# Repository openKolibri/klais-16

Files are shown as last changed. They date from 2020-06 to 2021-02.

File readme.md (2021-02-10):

![SIXTEEN]
![SEGMENT]
![DISPLAY]

# Sixteen Segment Display
The look of classic signage, be it neon tubes, wrought iron, or the use of distinctive typography and negative space, has a particular appeal. Unfortunately, the art form is dwindling due to the flexibility and flash that comes with newer LED arrays. Their distinctive styles have been giving way for the monotony of RGB LED panels.

![cycleGif]

The *Klais Display* series, in which this panel is the first item, was inspired by the early electronic displays still seen in relics bygone from an era of cigarette machines, electronics test equipment, and pinball machines. Its been modernized, enlarged, and made easily integrable into your own projects, while retaining its beauty and elegance.

![isoArray]

What follows below is highly detailed technical documentation. The [user guide][userGuide] is also available and focuses on integrating the display(s) into a project.

## Table of Contents
  * [Design](#design)
    * [Hardware](#hardware)
      * [LEDs](#leds)
      * [LED Driver](#led-driver)
      * [Microcontroller](#microcontroller)
      * [Power supply](#power-supply)
      * [Connections](#connections)
        * [Programming](#programming)
        * [Dataflow](#dataflow)
        * [Config Pads](#config-pads)
        * [Key Connector](#key-connector)
      * [Mounting](#mounting)
    * [Firmware](#firmware)
      * [Modes](#modes)
      * [UART](#uart)
        * [RX](#rx)
        * [TX](#tx)
      * [Brightness](#brightness)
      * [Timeout Refresh](#timeout-refresh)
      * [Display Driver](#display-driver)
        * [Protocol](#protocol)
        * [LED Number](#led-number)
        * [Segment Order](#segment-order)
      * [Configuration](#configuration)
        * [Baud Selection](#baud-selection)
      * [Compiling](#compiling)
      * [Flashing](#flashing)
  * [Absolute Maximum Ratings](#absolute-maximum-ratings)
  * [Guaranteed Ratings](#guaranteed-ratings)
  * [Manufacturing](#manufacturing)
    * [BOM](#bom)
    * [PCB-Assembly](#pcb-assembly)
    * [Physical Assembly](#physical-assembly)
    * [Production Scaling](#production-scaling)
      * [PCB Stack](#pcb-stack)
      * [Die Cut](#die-cut)
      * [Injection Moulding](#injection-moulding)
      * [Custom ASIC](#custom-asic)
    * [Programmer](#programmer)
      * [Minimal](#minimal)
      * [Production](#production)
    * [Artwork](#artwork)
    * [Labels](#labels)
    * [Inventory and QC](#inventory-and-qc)
    * [Part Numbers](#part-numbers)
  * [Safety](#safety)
  * [Certifications](#certifications)
  * [Licence](#licence)
  * [Attribution](#attribution)
    * [Fonts](#fonts)
    * [Libraries](#libraries)
  * [Reccomended Reading](#reccomended-reading)
  * [ToDo](#todo)

## Design
The display is a recreation of sixteen segment alphanumeric displays in a format that is physically larger and thinner than anything available on the viewing front. The modular segments can be combined to make a display of any length. It is designed to be easy to use and accessible. The physical design is based on stacking layers to provide clearance, a diffusion layer, and encapsulation for the electronics. The minimalist design and 3:2 aspect ratio were chosen to make integration very clean. There are no gaps between characters and when placed side-by-side, there is a flat near-seamless surface.

| NOON | MDNT | BASE |
| --- | --- | --- |
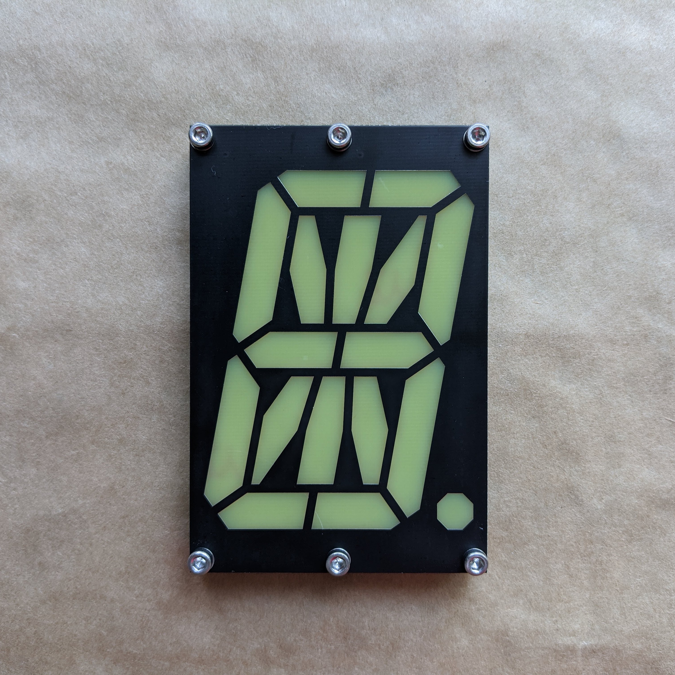
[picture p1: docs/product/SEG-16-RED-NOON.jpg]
SEG-16-RED-NOON
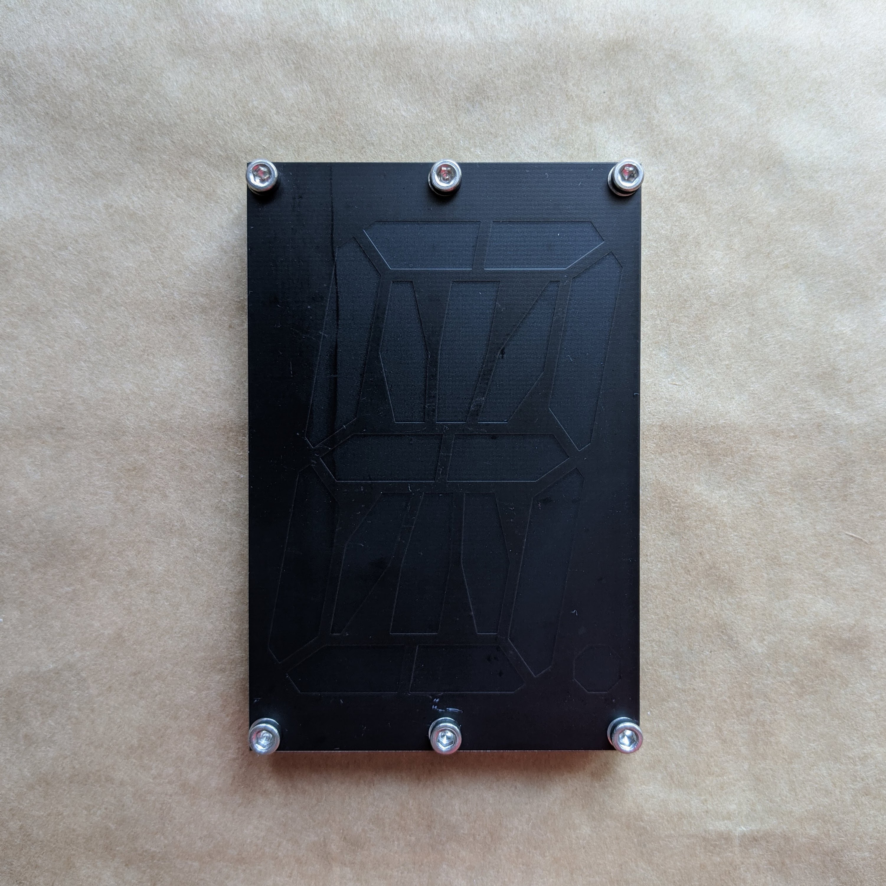
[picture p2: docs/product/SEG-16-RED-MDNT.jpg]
SEG-16-RED-MDNT
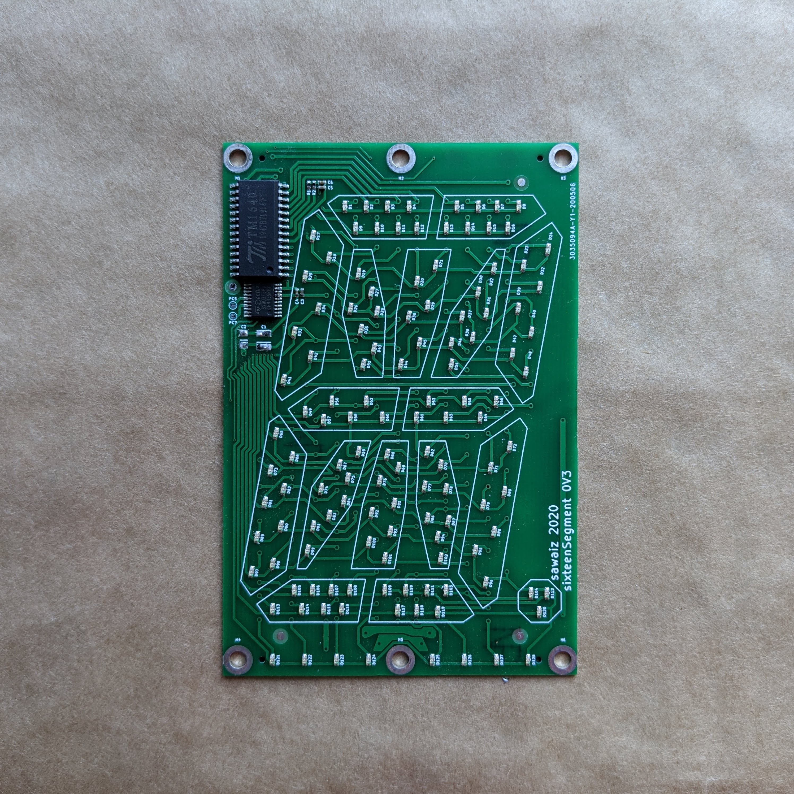
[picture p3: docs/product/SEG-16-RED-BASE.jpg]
SEG-16-RED-BASE
|  |  |  |

### Hardware
The panels are designed for efficient high yield manufacturing in both small and large quantities, with three possible stages, based on tooling investment. The physical size of each panel is `100 mm` x `66.66 mm`, providing a 3:2 aspect ratio and are nominally `5.8 mm` thick. Each panel weighs `63.97 g` with 6 plastic rivets.

![schematic]

A [schematic.pdf] is also available.

#### LEDs
The assembly uses 128 0603 surface mount LEDs. They are spaced evenly through all the segments, as well as eight of them acting as points in the underline. The 0603 (`60 mil` x `30 mil`, or `1.5 mm` x `0.8 mm`) package is used for their wide accessibility, providing a breadth of alternatives in color, lens projection angle, and brightness for possible substitutions. The datasheets for the LEDs used for each model is provided in the table below.

| Model | MPN | Detail | Current Draw |
| --- | --- | --- | --- |
| `SEG-16-RED-XXXX` | [KT-0603R] | ![IMG-KT-0603R] | [RED][asciiCurrent]  |

#### Led Driver
Titan Micro Electronic's [TM1640] ([english][TM1640ENG]) is used to control the LEDs. The device provides individual control of 128 LEDs in a 16x8 multiplexing configuration, has 8 levels of brightness adjustment, and provides a constant current supply of `20 mA`. It is rated for only `5V` but testing shows that, although with a slightly lower multiplexing frequency, it works quite well at `3.3V`. Communication is over a clocked serial link with a custom protocol and register mappings control the outputs. The 16 grids are rows, while the eight segments are the columns.

![IMG-TM1640]

This chip is made specifically for the Chinese market and may be hard to source in the west. Based on datasheets, it is easily swappable with identical components from other manufacturers, as shown below, in case the availability changes.

| Manufacturer | MPN |
| --- | --- |
| GN Semiconductors | GN1640 |
| Cmsemicon | CMS1640  |
| Wuxi I-CORE Electronics | AiP1640  |

#### Microcontroller
STMicroelectronics's [STM8S003] is a very low-cost microcontroller for cost sensitive applications, but provides a reasonable host of features. It has a wide voltage range of `2.95V` to `5.5V`, internal 16Mhz clock, UART that can be clocked at up to 1Mbps, plenty of timers, and 28 I/O. As well as other features that are not being used like a 10b ADC, SPI/I2C hardware, and low power modes.

![IMG-STM8S003]

#### Power supply
The input power is rated at `5V`, and the current drawn is dependent on the number of lit LEDs and the color of the display. Each segment has `100 uF` + `10 uF` of bulk capacitance, as well as decoupling on all the chips so it should be robust against a unstable power supply. There is no reverse polarity or overvoltage protection as that is the responsibility of the integrator. The table below shows some current draws, with the full table of all the models and characters [available][asciiCurrent] along with measurement methodology.

| Display  | `RED` Full Brightness (mA) | `RED` Min Brightness (mA) |
| --- | ---:| ---:|
| Off | 5.2 | 5.2 |
| All | 319.0 | 28.6 |
| `@` | 197.0 | 19.1 |
| `.` | 17.1 | 6.0 |
| `K` | 125.7 | 13.8 |
| `[` | 106.0 | 12.4 |

Maximum power draw is `1.6 W` at max brightness and all segments lit. Temperature rise above ambient after two hours is `15.9°C` (`61°F`).

#### Connections
The back of the module contains pads that are used for communication and configuration, providing many options to the end-user.

![config-back]

##### Programming
The four labeled pads near the top of the module are for programming. The STM8S uses a `SWIM` programming interface. The `4 mm` round pads are used to install the initial firmware and can be used for firmware updates or custom firmware if needed. The power pins are connected to the power rails, so they can also be used as power input or outputs.

![config-pgrm]

##### Dataflow
The five pads on each side are the connections that provide the data, as well as power rails, from one board to another. For basic functionality, lining up the boards and soldering the top three pads (`GND`, `TX/RX`, and `+5V`) is all that is needed, although soldering all five will provide more power rails and cause no issues.

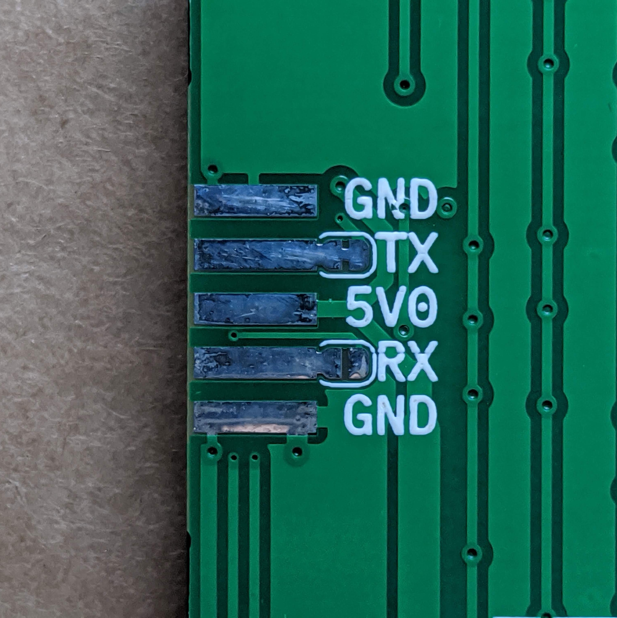
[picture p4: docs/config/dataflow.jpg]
config-dataflow


With the display facing you, the data comes in on the left on the `RX` pad, and flows out on the right via the `TX` pad. If the modules are soldered inverted, the connection is symmetric providing protection against swapping power supply rails.

If needed, the inverted configuration also provides the option of having two decimal points forming a colon. For this configuration to work, the solder jumper pads on the back will need to be reconfigured, cutting the top two and bridging the bottom, as shown in the diagram.

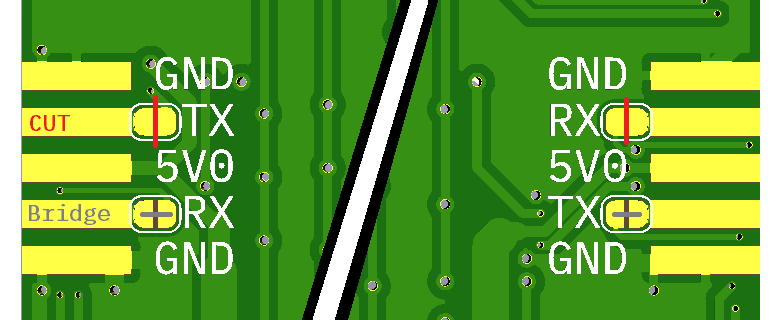
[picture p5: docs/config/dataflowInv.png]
config-dataflowInv


The moves the `RX` and `TX` lines to the correct sides to be placed inline with normally oriented modules.

##### Config Pads
The back has seven configuration pads that provide different settings and are checked on boot. By default, they are all unbridged. The configuration pads are to be selected with solder jumpers.

![config-config]

##### Key Connector
The front contains two optional unpopulated spring connectors Molex [0472861001]. These provide functionality if the thickness of the panel or reconfigurability is the main concern. By removing any solder joints on the back, and transmitting the data and power through the keyed connector. The thickness is limited to `5.8 mm`. The small PCB keys also allow assembly and construction of quick and easily reconfigurable arrays. The connectors are not always used, so they are not installed by default since they add cost and are not expected to be used by most.

![config-keyed]

The solder jumper marked `RTN_EN` enables the return channel on the last board. If a chain of displays is used and needs to be chained to the next row, this will send the signal back though one of the spring connector pins and make it available on the first display making a for a cleaner run of signal between rows.

#### Mounting
The mounting holes are placed `3 mm` from all edges and are for `M3` screws in a very close fit with a `3.1 mm` drill and though plated for a bit more ruggedness. A `#4` screw can be used as a imperial alternative. They are not connected to any nets, have a `5.5 mm` annular ring for screw heads, and are masked so if screws are not used, the annular ring surface matches the rest of the panel.

![mountingDim]

The holes and hardware provide a number of options for assembly and mounting.

| Mounting Method | Part Number | Component | Example |
| --- | --- | --- | --- |
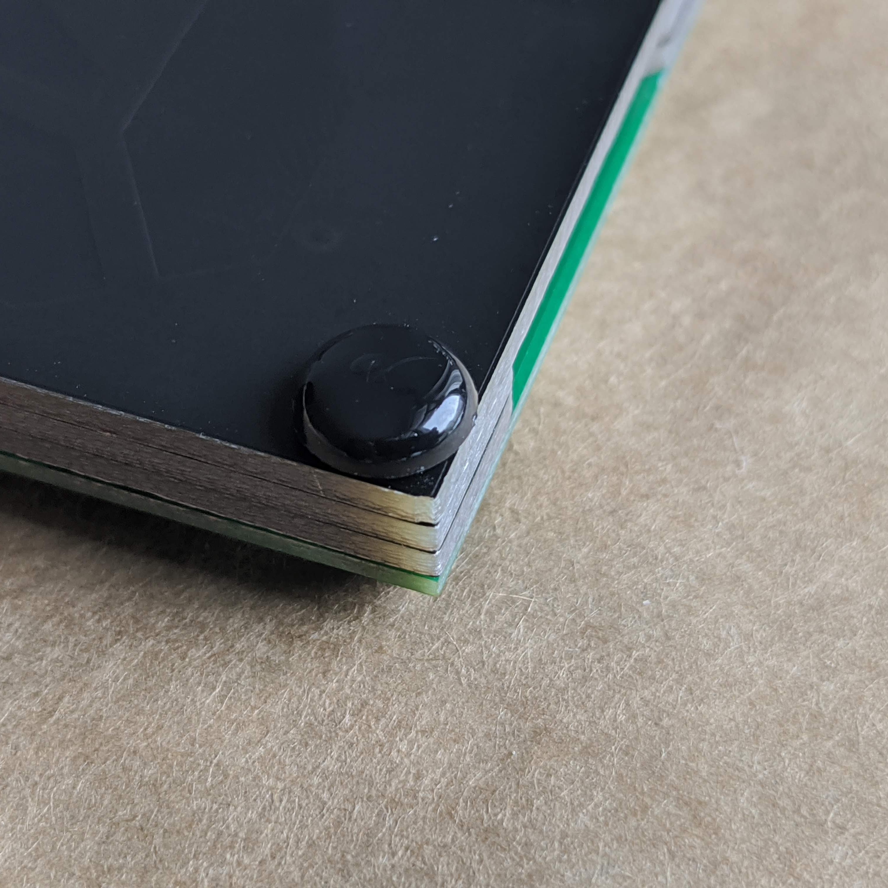
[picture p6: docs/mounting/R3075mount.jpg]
rivetInstalled
| Push Rivet `3 mm` x `7.5 mm` | [R3075] | ![plasticRivet] |  |
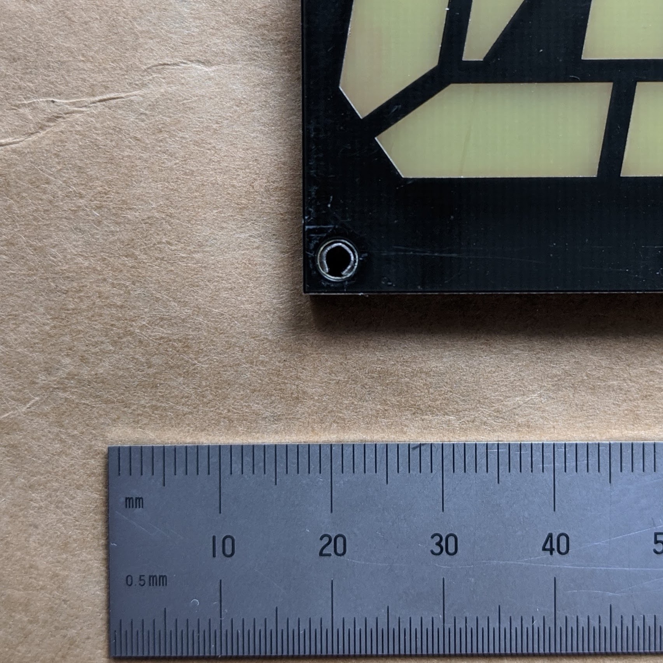
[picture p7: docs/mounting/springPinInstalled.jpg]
springPinInstalled
| Spring pin `3 mm` x `6 mm` | [97161A128] | ![springPin] |  |
| `M3x8x0.5` and Nut | [91292A112] [91828A211] | ![M3x8] | ![M3x8Installed] |
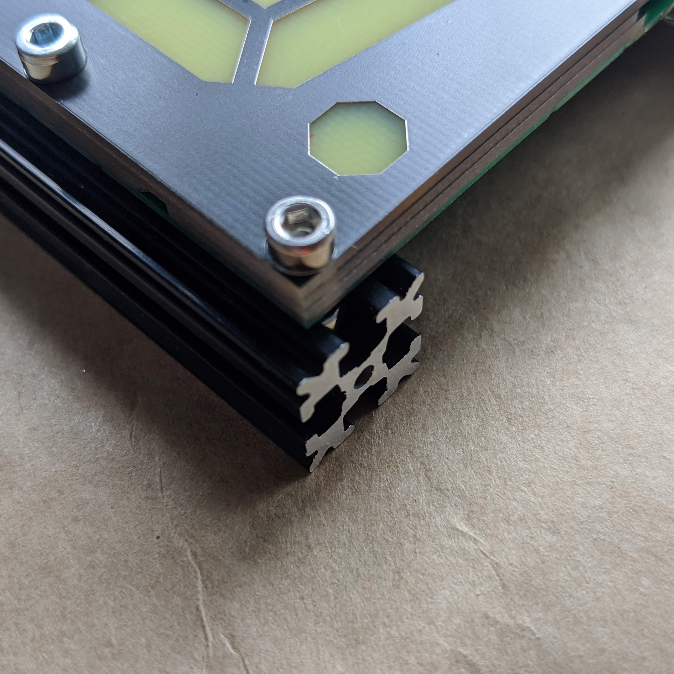
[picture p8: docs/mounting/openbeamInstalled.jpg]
openbeamInstalled
| `15 mm` Extrusion M3x10 | [Misumi HFS3], [OpenBeam], [Makerbeam XL] | ![openbeamParts]  |   |
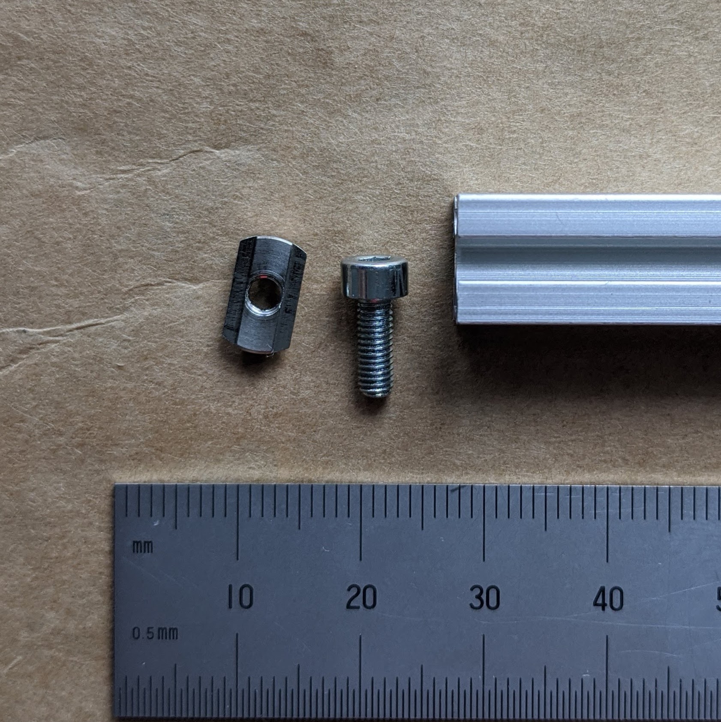
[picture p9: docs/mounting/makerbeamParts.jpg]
makerbeamParts
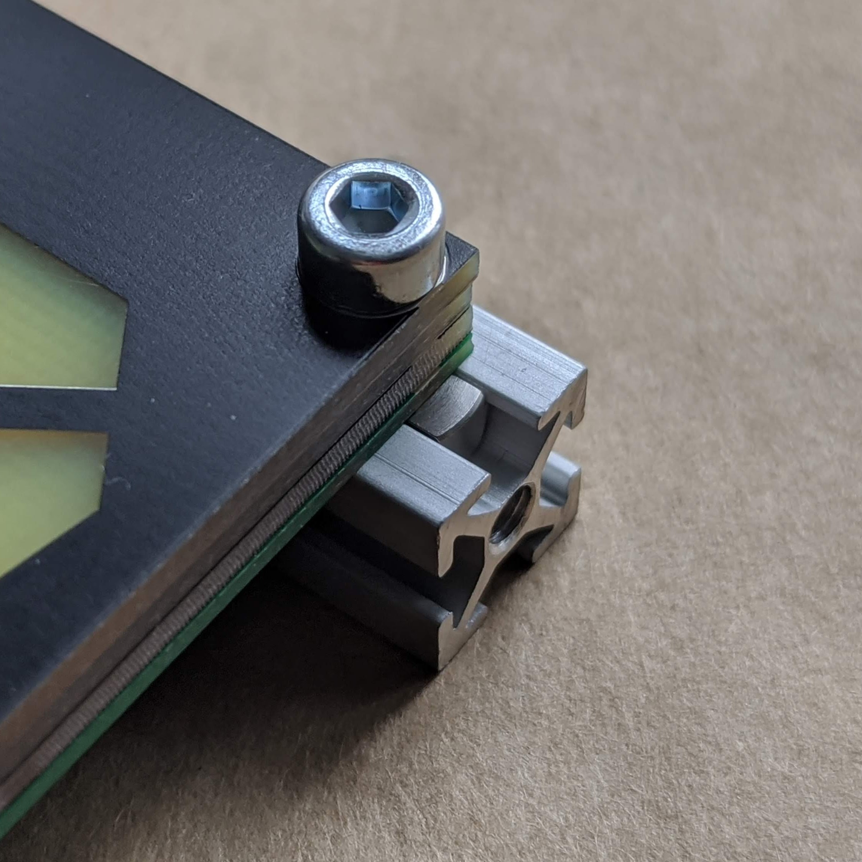
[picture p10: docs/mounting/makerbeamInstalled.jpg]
makerbeamInstalled
| `10 mm` Extruison M3x8 | [MakerBeam], [MicroRAX] |  |  |
| `20 mm` Extrusion Slot | [Misumi HFS5], [Metric 8020] | ![2020Extrusion]  | ![2020Installed] |
| Soldered brass nut | [90690A037] | | |
| Zip Ties `3 mm` | | | |
| #4 screw, machine or wood | | | |
| Pop rivets, M3 or #4 | | | |

### Firmware
The firmware is written in C and is fully interrupt driven. It uses the [STM8 standard periphiral library][STM8SPL] (SPL) and provides multiple modes of controlling the display through commands. All code shown is simplified pseudocode.

#### Modes
By default the display boots in the `ASCII` character mode operating as a state-machine making changes based on each byte received. When enough bytes have been received for the command, the device shifts back into `ASCII` mode.

| Mode | Control Byte | Bytes | Notes |
| --- | --- | -----:| --- |
| ASCII | None | 0 | Displays ASCII cahrachter |
| Segment | 0x11 `DC1` | 3 | Control individual segments |
| LED | 0x12 `DC2` | 16 | Control individual LEDs |
| Brightness | 0x13 `DC3` | 1 | Set brightness |

**Only ASCII mode is verified in firmware version 0.6 other modes are in beta**

#### UART
The UART hardware is used to receive and transmit data from a module to another. Communication is through an 8 bit NRZ with one start bit and one stop bit encoding with no parity and the default baud rate is `115200 bps`. The voltage levels are the module power voltage, nominally `5V`.

The UART is initialized on boot and the receive interrupt is enabled. When a new character has been read in the receive buffer, the interrupt fires.

##### RX
Based on the receive mode the new data is loaded into the receive buffer. A number of consecutive bytes read is dependent on the mode that is set. A mode byte received after mode has been reset will change the mode as well. The transmit interrupt is fired when a new byte is received and the buffer is full, depending on the current receive mode.

##### TX
The first byte is sent by the interrupt trigger. Depending on the transmit mode, the interrupts continue to fire, stepping down through the buffer until it is empty, outputting the data in the same order as it was received.

#### Brightness
There are nine brightness levels including blanking. They are accessed with sending the brightness mode selector followed by the brightness code.

| Level | Code (HEX) | Code (DEC) |
| -----:| --- | ---:|
| OFF | 0x81 | 129 |
| 1 | 0x88 | 136 |
| 2 | 0x89 | 137 |
| 4 | 0x8A | 138 |
| 10 | 0x8B | 139 |
| 11 | 0x8C | 140 |
| 12 | 0x8D | 141 |
| 13 | 0x8E | 142 |
| 14 | 0x8F | 143 |

#### Timeout Refresh
A display refresh timeout is implemented so the display only updates when there is a pause in the data. This prevents the display from flickering with intermediate data when a stream of data is being loaded into an array. This also updates all displays at the exact same time, since the time from the last byte is the same across all displays in an array.

```c
UART_RX_INTERRUPT() {
  TIMER_SET(0x00);
  TIMER(INTERRUPT, ENABLE);

  // Remaining RX routine ...
}
```

Every time a new character is received in the RX buffer, a timeout is started of 1 ms (*to be replaced with 2.5 byte time based on baud rate*). If a new character comes before the timeout is reached, it is reset again. When the timeout is reached, the overflow interrupt is triggered. In the interrupt, the further interrupts are disabled and then the display is drawn based on the TX mode.

```c
TIMER_INTERRUPT(){
  TIMER(INTERUPT, DISABLE);
    switch (txMode) {
        case LED_CONTROL:
          showLeds(data);
          break;
        case SEGEMENT_CONTROL:
          showSegments(data);
          break;
        case BRIGHTNESS_CONTROL:
          setBrightness(data);
          break;
        default:
          showLetter(data);
    }
}
```

#### Display Driver
The display driver is a minimal custom library. The display driver is controlled over a clocked serial link with a custom protocol. The LEDs are multiplexed based on the internal memory that stores a 1b value for each LED.

The chip has only a few registers, most of which make up the current LED states. They are all described in the header file and fall into three sections.

- Data Commands
- Grid Memory
- Display Brightness

##### Protocol
A few requirements define the protocol.

- Default state for both clock and data is high
- Start condition is data going low followed by clock going low
- A bit is read when the clock is pulsed positive
- Data cannot change while clock is high
- End condition is clock high followed by data high
- 8 bits per byte, LSB First

![TM1640Timing]

Registers are set by sending a command byte followed by a optional data byte based on the command. A set of commands can be sent if auto increment mode is set by not fulfilling the end condition and sending the next byte immediately.

![dataCapImg]

A Saleae logic [capture][dateCapFile] is also provided.

##### LED Number
The LEDs are placed in a grid-like pattern, so a conversion is needed to map each LED to the segment it's in. [segmentMapping.h] contains arrays that map the LED's reference designator to each segment. This still needs to be converted into the segments and grid from the LED number. The formula below is used to make those conversions.

```
GRID = ((REF-1) / 8) + 1
SEG = (REF-1) % 8
```

##### Segment Order
Besides direct control over the LEDs, there are also helper functions such as segment control and print letter. These use the [segmentMapping.h] and [sixteenSegments.h] headers. Once the LEDs are mapped to the segments, the segments are mapped to the ASCII character set. [sixteenSegments.h] contains which segments need to be lit for each character, the notation used in both files refers to the segments in clockwise order going in as-is conversion with sixteen segment displays.

![segmentMap]

#### Configuration
On boot, the seven GPIO for the configuration pads have their internal pullups enabled and are then set as inputs. They are all sampled. Any that have been bridged to ground will read as low and their inverted state can be used to set the configuration.

```c
  uint8_t config = 0x00;
  config |= !read(PIN_0) << 0;
  config |= !read(PIN_1) << 1;
  config |= !read(PIN_2) << 2;
  config |= !read(PIN_3) << 3;
  config |= !read(PIN_4) << 4;
  config |= !read(PIN_5) << 5;
  config |= !read(PIN_6) << 6;
```

The pads have functions attached to them, some are just switches, while others join together in a binary segment to allow multiple selections.

| Pad | Function | Status |
| ---:| --- | --- |
| 0 | Inverted Display | Not implemented |
| 1 | Baud (Bit 3) | Implemented in 0.6 |
| 2 | Baud (Bit 2) | Implemented in 0.6 |
| 3 | Baud (Bit 1) | Implemented in 0.6 |
| 4 | Baud (Bit 0) | Implemented in 0.6 |
| 5 | Pending | Open for Development |
| 6 | Pending | Open for Development |

##### Baud Selection
Pads `[4:1]` allow baud selection, the default is `115200` as it is a common bitrate that is available on most computer and microcontrollers and is reasonably fast for most applications.

| Pad 4 | Pad 3 | Pad 2 | Pad 1 | Selected Baud |
| -----:| -----:| -----:| -----:| ---:|
| 0 | 0 | 0 | 0 | 115200 |
| 0 | 0 | 0 | 1 | 110 |
| 0 | 0 | 1 | 0 | 300 |
| 0 | 0 | 1 | 1 | 600 |
| 0 | 1 | 0 | 0 | 1200 |
| 0 | 1 | 0 | 1 | 2400 |
| 0 | 1 | 1 | 0 | 4800 |
| 0 | 1 | 1 | 1 | 9600 |
| 1 | 0 | 0 | 0 | 19200 |
| 1 | 0 | 0 | 1 | 38400 |
| 1 | 0 | 1 | 0 | 57600 |
| 1 | 0 | 1 | 1 | 128000 |
| 1 | 1 | 0 | 0 | 230400 |
| 1 | 1 | 0 | 1 | 256000 |
| 1 | 1 | 1 | 0 | 460800 |
| 1 | 1 | 1 | 1 | 1000000 |

It is tested with a 4 bit mask and right-shifted to get numbers 0-15 from the config byte.
```c
uint32_t bauds[16] = {115200, 110, /*...*/, 460800, 1000000};
uint32_t baud = bauds[(config & 0X1E) >> 1];
```

#### Compiling
It is setup to be compiled through [PlatformIO]. More information can be found through its [documentation][platformIODocs]. Changes may be made to the settings in the `ini` file.

#### Flashing
The [programming pads](#programming) on the back are used to program the module. An ST-Link V2 with the SWIM protocol is used to upload the firmware.

Uploading using PlatformIO is currently used. Refer to [documentaiton][platformIODocs]. Changes may be needed to the `ini` file settings.

We also use a custom bash script internally that uploads, tests, and updates our database. It uses STM8Flash on Linux machines and ST Visual Programmer on WSL.

## Absolute maximum ratings
**To be tested, don't have the power supply, or really the heart to kill a module just yet.**

Works fine down to 3.3V.

## Guaranteed ratings

| Mesurement | Value | Unit | Tolerence |
| --- | -----:| ---- | --- |
| Power Supply | 5.0 | V | ± 0.2 |
| Max current  | 319 | mA | ± 5% |
| Max Temp | 60 | C | |
| Min Temp | -20 | C | |

## Manufacturing
Designing for manufacturing was a large portion of this project. This was done through many approaches on a number of fronts.

### BOM
The BOM was selected with parts that are common to the Chinese high-volume manufacturing market, have strong supply chains, as well as many alternatives in case a supplier stops manufacture. The number of unique parts was kept to a minimum and the maximum amount of features can be implemented with "free" options, like SMD pads. The table of BOM is shown below.

| REF | QTY | Manufacturer | MPN | Description |
| --- | ---:| --- | --- | --- |
| C1 | 1 | AVX | TAJB107K006RNJ | CAP: Tantalum 100uF 6.3V CASE-B_3528 |
| C2 | 1 | AVX | TAJA106K016RNJ | CAP: Tantalum 10uF 16V CASE-A_3216 |
| C3 C6 | 3 | Samsung Electro-Mechanics  | CL05A105KA5NQNC  | CAP: MLCC 1uF 25V 0402 |
| C4 C5 C7  | 2 | Samsung Electro-Mechanics  | CL05B104KO5NNNC  | CAP: MLCC 100nF 16V 0402 |
| D1-D128 | 128 | Hubei KENTO Elec | KT-0603R | LED: RED 520-625nm 90-100mcd@20mA 0603 |
| R1 R2 | 2 | Uniroyal Elec | 0402WGF1002TCE | RES: 10K 1% 1/16W 0402 |
| U1 | 1 | STMicroelectronics | STM8S003F3P6TR | MCU: 8b 16Mhz 8k Flash 128B EEPROM TSSOP-20 |
| U2 | 1 | Shenzhen Titan Micro Elec  | TM1640 | DRV: 16x8 LED Driver SOP-28 |

The [Octopart] BOM is also available, although not much use since the parts are not carried by US distributors.

### PCB-Assembly
The PCB assembly is single-sided surface mount components only. The smallest components are 0402. All can be PNP from tapes or tubes, and reflowed at once. There are three fiducials as well as three tooling holes on each board. The tooling holes are `1.152 mm` and the fiducials are `1.5 mm` x `3 mm`. There are 139 components all of which are SMD, yielding a total of 322 solder joints.

![assembly]

### Physical Assembly
The panels are combined in order and can be held together with `3 mm` x` 7.5 mm` nylon 6/6 push rivets. This makes ingress into inventory much faster, and gives the customer another option to use for mounting since it's an uncommon part.

### Production Scaling
The physical assembly varies in the volume of production. Further sections will be updated with information if we ever reach those volumes.

#### PCB Stack
First iteration is the PCB stack as that has no tooling cost and all can be order from the same manufacturer. There are four PCBs in the stack that make-up the display.

| Board | Height (mm) | Width (mm) | Layers | Copper  | Thickness (mm) | Material | Min Drill (mm) | Trace Sizing | Mask  | Silk | E-Test |
| ----- | ---:| ---:| ---:| ---:| ---:| --- | ---:| ---:| ----- | --- | --- |
| L0 | 100.00 | 66.66 | 2 |  1.0 oz | 1.0 | FR4 | 0.3 | 6/6 | Green |  White | Yes |
| L1 | 100.00 | 66.66 | 2 |  1.0 oz | 1.6 | FR4 | N/A | N/A | Black |  White | No |
| L2 | 100.00 | 66.66 | 2 |  1.0 oz | 1.6 | FR4 | N/A | N/A | Black |  White | No |
| L3 | 100.00 | 66.66 | 2 |  1.0 oz | 1.6 | FR4 | N/A | N/A | Black |  White | No |

The bottom board is the electrical board containing all the components and signals, and is used for all iterations. The following two boards provide spacing and separation for the diffusion of the LEDs, as well as cut outs for the other components, and the final board provides diffusion and a solid panel for the front face. The layout of each layer is shown in the table below.

| L0  | L1  | L2  | L3  |
|:-----:|:-----:|:-----:|:-----:|
| ![L0] | ![L1] | ![L2] | ![L3] |

PCB stack is best for quantities below 500 units.

#### Die Cut
The die cut panels replace the top three panels with `1/16"` plastic that is die cut. This is faster to manufacture and less expensive, since we do not need the copper, silk, or mask layers. Also, uses a through-opaque material instead of the FR4 providing better protection from light bleed.

| L1 | L2 | L3 |
|:---:|:---:|:---:|
| ![L1-DIE] | ![L2-DIE] | ![L3-DIE] |

Switch to die cut at 1k-10k units.

#### Injection Moulding
Injection moulded panel will replace the front three panels with a single injection moulded plastic part, as well as the screws. Providing the option to either punch through from the front to get the same M3 holes, or screw in from the back to have a completely clean front panel. The IM part also provides other benefits, such as, a more consistent texture on the whole panel, and a high contrast front that has no discernible pattern when off.

![imProto]

A test model was made with 2.5 deg draft angles and `1.2 mm` wall thickness for ABS moulding. Approximate calculations show tooling costs of $7.5k for production steel tooling, and 15s cycle time.

Switch to IM at 20k-100k units.

#### Custom ASIC
Flipchip LEDs with COB fully integrated controller. HDL gateware design to begin at 50k units. RISC-V processor with 16x16 multiplexing LED array at a 72 MHz PLL clock.

[Hey, a girl can dream. Chip die image]

Engineering and silicon die cost around $50k tooling (maybe? I don't really know, but I could probably synthesize a sea of gates design that works) Switch to custom ASIC at 100k units.

### Programmer
The chip needs to be programmed with the firmware and tested for proper operation before sending out to customers. Two programmers are designed. First, a low cost simple programmer for smaller quantities and available on special request for those who want to customize the firmware, and the other is a completely independent production-ready programmer and tester.

#### Minimal
Them minimal program has holes for alignment corresponding to the top row, and four spring pins. These connect out to the programming header which can then be corrected to an ST-Link V2. The alignment holes have M3x8 screws and nuts which were added to create alignment pins. The board to be programmed is aligned with the pin and held down while programming.

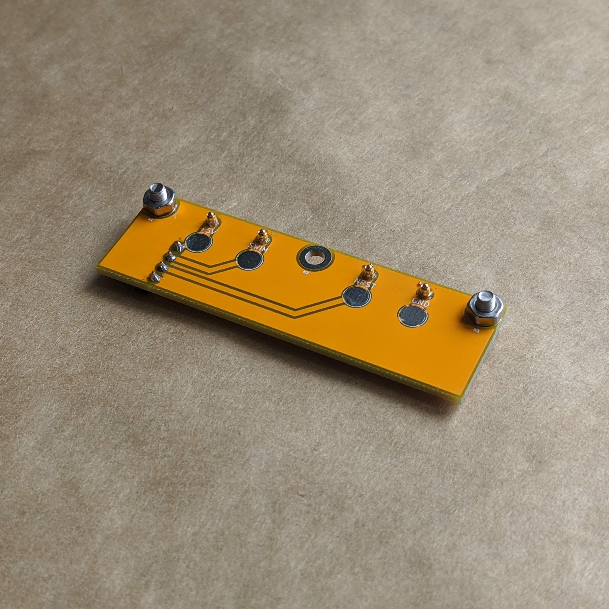
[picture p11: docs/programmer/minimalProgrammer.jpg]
minimalProgrammer


#### Production
The production programmer is a program and test jig. The boards are slipped under the bottom overhang and pushed down until the lever snaps and holds them in place. Then a full test suite can be run, checking the input and output, programming with multiple firmwares and reading back system outputs to verify that the device works properly.

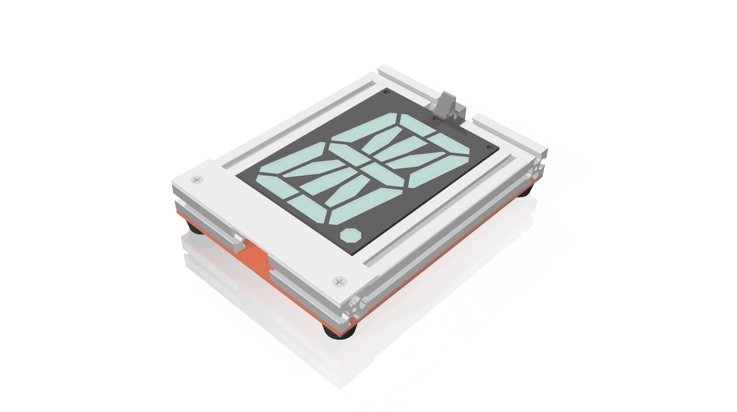
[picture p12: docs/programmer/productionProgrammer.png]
productionProgrammer


### Artwork
The artwork on the back is a trademark and protected by copyright. This can not be duplicated on derivative works. It consists of the Kolibri bird, copyright and designer notices, certifications, a location for labeling, as well as the URL and QR code to documentation.

### Labels
The back has a location for a `38 mm` x `13 mm` label from a Brother `38 mm` continuous label. This label can have serial number, batch numbers, the model number, and any other device specific information.

![config-label]

### Inventory and QC
Inventory can then be managed with QR coded serialized tags. The serialization also provides better QC as it allows failure analysis and tracking in case of issues traceable to the batch and assembly level.

### Part Numbers
The manufacturer part number is based on the following scheme.

MPN: `SEG-16-AAA-BBBB`

Where `AAA` is the three character code for color

| Code | Color |
| --- | --- |
| `RED`  | Red |
| `GRN`  | Green |
| `BLU`  | Blue |
| `RGB`  | Red Green Blue |
| `WHT`  | White (5000k) |
| `WWT`  | Warm White (3500k) |
| `YEL`  | Yellow |

And `BBBB` denotes the face type

| Code | Face Type |
| --- | --- |
| `NOON` | Noon face, Exposed FR4 |
| `MDNT` | Midnight face. Black soldermask |
| `PLEX` | Acrylic Laser Cut |
| `IM  ` | Injection Moulded |

## Safety
The assembly is almost exclusively made from FR4. It is highly fire retardant and will not burn after a flame is removed.

The edges are milled, but it is possible to have small pieces that could cause cuts, abrasions, or become embedded in the skin. If sanding or milling the board, use a respirator as fiberglass dust is carcinogenic.

The boards are assembled in a lead-free process and all components are RHOS certified.

The low voltage `3.0`-`5.5V` as well as the currents used pose very little risk to healthy humans.

## Certifications
Certifications take time and effort but will make a better product by guaranteeing its safety to users and let them use it in other projects. The table below shows the order we will be trying to obtain certifications.

| Cetrtifing Authority | Status |
| ---| --- |
| OSHW | [DE000087] |
| CE | No  (Self Certification)  |
| FCC | No  (Self Certification)  |
| UL Registered Component  | No  (yearly fee) |
| WEEE | No  (yearly fee) |

## Licence
The product was designed by Sawaiz Syed for Kolibri who owns the copyright. Everything is released under permissive copyleft licenses, and copies of all licenses are included.

| Sector | License | Verison |
| --- | --- | ---:|
| Hardware | [CERN-OHL-S] | 2.0 |
| Firmware | [GNU GPL] | 3.0 |
| Documentation | [CC BY-SA] | 4.0 |

Copies of all licenses are required with the distribution of files. All files are available in easy-to-modify types for remixing. Please purchase original products from Kolibri to support further products, design, and research.

## Attribution
As with everything, this too is built on the gracious support of previous projects.

- KiCad
- Inkscape
- Blender
- SDCC
- STM8Flash
- PlatfromIO

### Fonts
- [DejaVu]
- [IBM Plex Mono]

### Libraries
- [Sixteen Segment ASCII](https://github.com/dmadison/LED-Segment-ASCII) - MIT - Copyright (c) 2017 David Madison
- STM8 SPL (Available component, but not included)

## Recommended Reading

## Todo
- [ ] Switch from SPL to just C and registers or [open headers](https://github.com/gicking/STM8_headers)
- [ ] Change from PlatformIO to a makefile
- [ ] Implement inverted font

<!-- Files -->
[KT-0603R]:               ./pcb/SEG-16-XXX-XXXX-L0/components/KT-0603R/KT-0603R.pdf
[TM1640]:                 ./pcb/SEG-16-XXX-XXXX-L0/components/TM1640/TM1640.pdf
[TM1640ENG]:              ./pcb/SEG-16-XXX-XXXX-L0/components/TM1640/TM1640-ENG.pdf
[STM8S003]:               ./pcb/SEG-16-XXX-XXXX-L0/components/STM8S003/STM8S003.pdf
[0472861001]:             ./pcb/SEG-16-XXX-XXXX-L0/components/0472861001/0472861001.pdf
[schematic.pdf]:          ./pcb/SEG-16-XXX-XXXX-L0/SEG-16-XXX-XXXX-L0.pdf
[segmentMapping.h]:       ./firmware/include/segmentMapping.h
[sixteenSegments.h]:      ./firmware/include/sixteenSegments.h

<!-- Links -->
[Octopart]:               https://octopart.com/bom-tool/6sdiCse8
[97161A128]:              https://www.mcmaster.com/97161A128
[91292A112]:              https://www.mcmaster.com/91292A112
[91828A211]:              https://www.mcmaster.com/91828A211
[90690A037]:              https://www.mcmaster.com/90690A037
[R3075]:                  https://www.amazon.com/gp/product/B07Z1XCS3M/ref=ppx_yo_dt_b_asin_title_o00_s00?ie=UTF8&psc=1
[Misumi HFS3]:            https://us.misumi-ec.com/vona2/detail/110300465870/
[Misumi HFS5]:            https://us.misumi-ec.com/vona2/detail/110302683830
[MakerBeam]:              https://www.makerbeam.com/makerbeam/makerbeam-10x10mm-profile-lengths-anodised-in-clea/
[Makerbeam XL]:           https://www.makerbeam.com/makerbeamxl/makerbeamxl-15x15mm-profile-lengths-anodised-in-cl/
[OpenBeam]:               https://www.makerbeam.com/openbeam/openbeam-15x15mm-profile-lengths-anodised-in-black/
[MicroRAX]:               http://www.microrax.com/
[Metric 8020]:            https://8020.net/20-2020.html
[STM8SPL]:                https://www.st.com/en/embedded-software/stsw-stm8069.html
[PlatformIO]:             https://platformio.org/
[platformIODocs]:         https://docs.platformio.org/en/latest/

<!-- Internal Links -->
[userGuide]:              ./docs/userGuide.md
[asciiCurrent]:           ./docs/asciiCurrent.md
[configTable]:            ./docs/configTable.md

<!-- Images -->
[SIXTEEN]:                ./docs/title/SIXTEEN.png                                               "SIXTEEN Rendered on display"
[SEGMENT]:                ./docs/title/SEGMENT.png                                               "SEGMENT Rendered on display"
[DISPLAY]:                ./docs/title/DISPLAY.png                                               "DISPLAY Rendered on display"
[isoArray]:               ./docs/product/isoArray.jpg                                            "Isometric view of a few panels lit with time"
[SEG-16-RED-NOON]:        ./docs/product/SEG-16-RED-NOON.jpg                                     "Top view of a NOON"
[SEG-16-RED-MDNT]:        ./docs/product/SEG-16-RED-MDNT.jpg                                     "Top view of a MDNT"
[SEG-16-RED-BASE]:        ./docs/product/SEG-16-RED-BASE.jpg                                     "Top view of a BASE"
[angledShow]:             ./docs/product/angledShow.jpg                                          "Angled shot of two panels"
[cycleGif]:               ./docs/char/char8M.gif                                                 "Animated gif of full ASCII cycle"
[schematic]:              ./docs/assembly/schematic.png                                          "Full schematic of design"

<!-- Config -->
[config-back]:            ./docs/config/backPanel.jpg                                            "View of entire back panel"
[config-pgrm]:            ./docs/config/pgrm.jpg                                                 "Detail of the program pads"
[config-dataflow]:        ./docs/config/dataflow.jpg                                             "Detail of the data flow connector and jumpers"
[config-dataflowInv]:     ./docs/config/dataflowInv.png                                          "Soldering instructions on traces to cut and bridge"
[config-config]:          ./docs/config/config.jpg                                               "Detail of configuration pads"
[config-keyed]:           ./docs/config/keyed.jpg                                                "Detail of keyed spring connector"
[config-label]:           ./docs/config/label.png                                                "Example of label"

<!-- Firmware -->
[TM1640Timing]:           ./docs/firmware/TM1640Timing.png                                       "Timing diagram of T1640 Protocol"
[dateCapFile]:            ./docs/firmware/fullDisplayCommand.sal                                 "Saleae logic analyzer file"
[dataCapImg]:             ./docs/firmware/dataCapImg.png                                         "Image of data capture"
[segmentMap]:             ./docs/firmware/segmentMap.png                                         "Letters to physical segment"

<!-- Mounting Options -->
[mountingDim]:            ./docs/mounting/mountingDim.png                                        "Dimensioned drawing of mounting holes and physical size"
[plasticRivet]:           ./docs/mounting/R3075.jpg                                              "Plastic rivet with ruler"
[rivetInstalled]:         ./docs/mounting/R3075mount.jpg                                         "Plastic rivet installed"
[2020Extrusion]:          ./docs/mounting/2020Extrusion.jpg                                      "20mm Aluminum Extrusion"
[2020Installed]:          ./docs/mounting/2020Installed.jpg                                      "Example of display mounted in 2020 extrusion"
[M3x8]:                   ./docs/mounting/M3x8.jpg                                               "M3x8 screw and nut"
[M3x8Installed]:          ./docs/mounting/M3x8Installed.jpg                                      "Module assembled with screw and nut"
[makerbeamParts]:         ./docs/mounting/makerbeamParts.jpg                                     "Parts for mounting on MakerBeam"
[makerbeamInstalled]:     ./docs/mounting/makerbeamInstalled.jpg                                 "Example installation on makerbeam"
[openbeamParts]:          ./docs/mounting/openbeamParts.jpg                                      "Parts for mounting on OpenBeam"
[openbeamInstalled]:      ./docs/mounting/openbeamInstalled.jpg                                  "Example installtion on OpenBeam"
[springPin]:              ./docs/mounting/springPin.jpg                                          "Spring pins with ruler"
[springPinInstalled]:     ./docs/mounting/springPinInstalled.jpg                                 "Example of spring pin installation"

<!-- Assembly -->
[assembly]:               ./docs/assembly/assembly.png                                           "Assembly diagram"
[L0]:                     ./docs/assembly/L0.png                                                 "Layer 0 layout"
[L1]:                     ./docs/assembly/L1.png                                                 "Layer 1 layout"
[L2]:                     ./docs/assembly/L2.png                                                 "Layer 2 layout"
[L3]:                     ./docs/assembly/L3.png                                                 "Layer 3 layout"
[L1-DIE]:                 ./docs/assembly/L1-DIE.png                                             "Layer 1 die cut outline"
[L2-DIE]:                 ./docs/assembly/L2-DIE.png                                             "Layer 2 die cut outline"
[L3-DIE]:                 ./docs/assembly/L3-DIE.png                                             "Layer 3 die cut outline"
[imProto]:                ./docs/assembly/imProto.png                                            "Prototype injection moulding model render"

<!-- Programmer -->
[minimalProgrammer]:       ./docs/programmer/minimalProgrammer.jpg                               "Minimal programmer picture"
[productionProgrammer]:    ./docs/programmer/productionProgrammer.png                            "Production programmer render"

<!-- Components -->
[IMG-KT-0603R]:           ./pcb/SEG-16-XXX-XXXX-L0/components/KT-0603R/KT-0603R.jpg              "Led componet image"
[IMG-TM1640]:             ./pcb/SEG-16-XXX-XXXX-L0/components/TM1640/TM1640.jpg                  "Led driver componet image"
[IMG-STM8S003]:           ./pcb/SEG-16-XXX-XXXX-L0/components/STM8S003/STM8S003.jpg              "Microcontorller part image"
[IMG-TAJA106K016RNJ]:     ./pcb/SEG-16-XXX-XXXX-L0/components/TAJA106K016RNJ/TAJA106K016RNJ.jpg  "Bulk capacitor image"
[IMG-TAJB107K006RNJ]:     ./pcb/SEG-16-XXX-XXXX-L0/components/TAJB107K006RNJ/TAJB107K006RNJ.jpg  "Bulk capacitor image"

<!-- Certifications -->
[DE000087]:               https://certification.oshwa.org/de000087.html

<!-- Licence -->
[CERN-OHL-S]:             ./pcb/LICENSE
[GNU GPL]:                ./firmware/LICENSE
[CC BY-SA]:               ./docs/LICENSE

<!-- Attribution -->
[DejaVu]:                 https://dejavu-fonts.github.io/
[IBM Plex Mono]:          https://www.ibm.com/plex/

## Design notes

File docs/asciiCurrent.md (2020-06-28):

# ASCII Power Chart
This applicaiton note shows the current drawn by each of the ASCII configurations of the sixteen segment display.

## Methodology
A single display is wired though uCurrent on the mA range. Connected to a single panel. A bash sctipt running on a pi-zero goes thougth entire ASCII set. A multimeter reads the output voltage as a current.

Tested at various brightnesses, no complete coverage just yet. Colums are notated as `LED.BRIGHTNESS_LVL`. All mesurements are in mA.

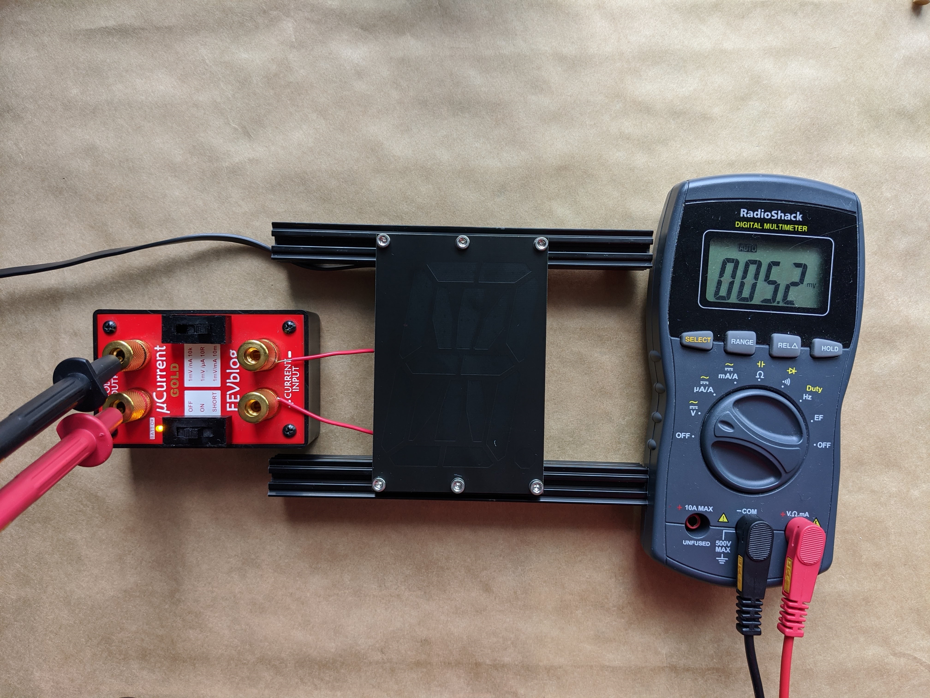
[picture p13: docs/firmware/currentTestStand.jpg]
currTest


| ASCII Code | Char | Example | `RED.14` | `RED.13` | `RED.12` | `RED.11` | `RED.10` | `RED.04` | `RED.02` | `RED.01` |
| ---:| --- | --- | ---:| ---:| ---:| ---:| ---:| ---:| ---:| ---:|
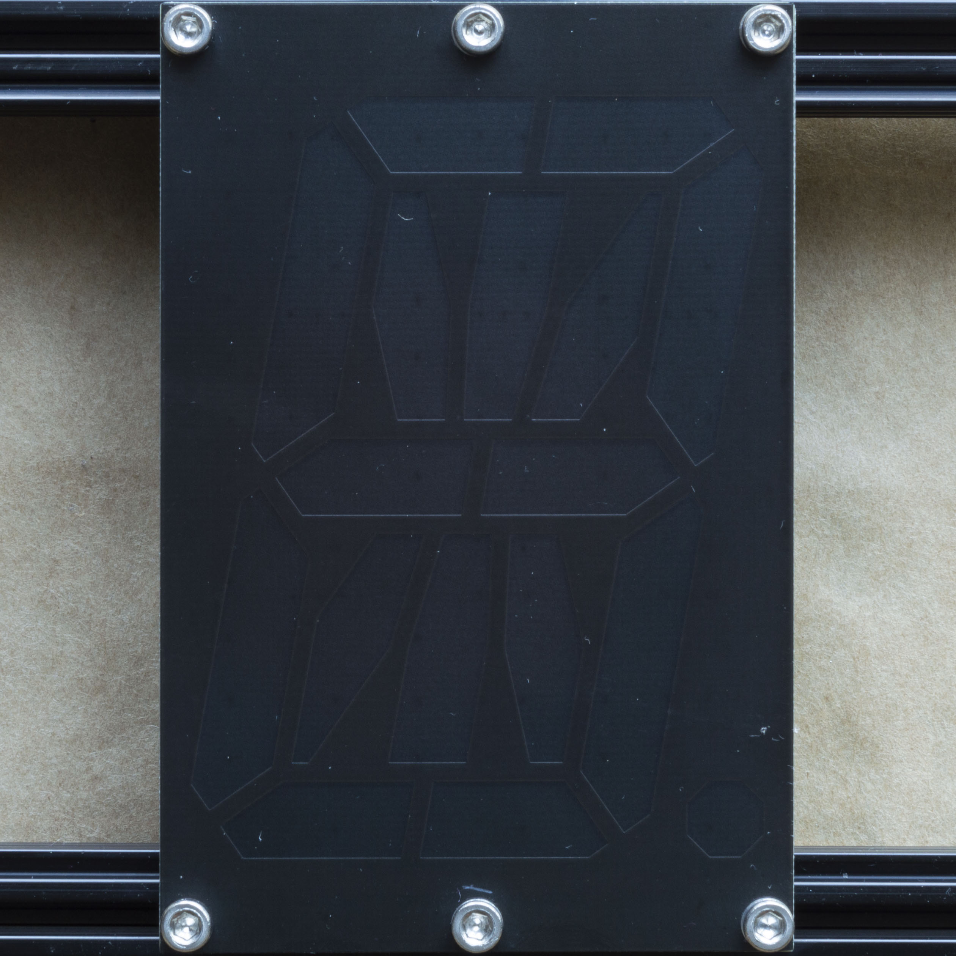
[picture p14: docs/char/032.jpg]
| 32 | ` ` |   | 5.2 | 5.2 | 5.2 | 5.2 | 5.2 | 5.2 | 5.2 | 5.2 |
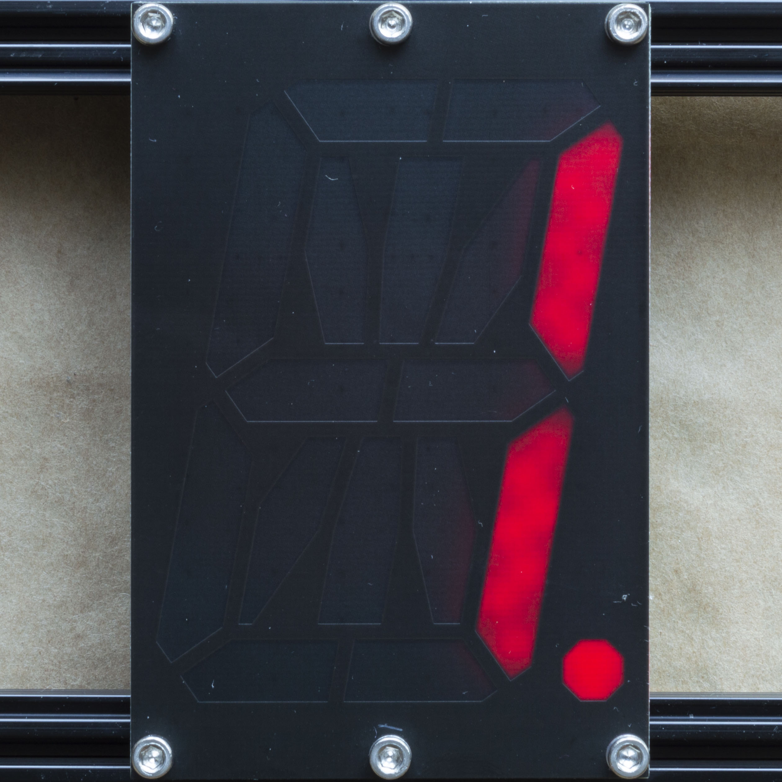
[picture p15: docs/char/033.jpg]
| 33 | `!` |   | 69.6 | 64.1 | 59.6 | 54.8 | 50.9 | 23.6 | | |
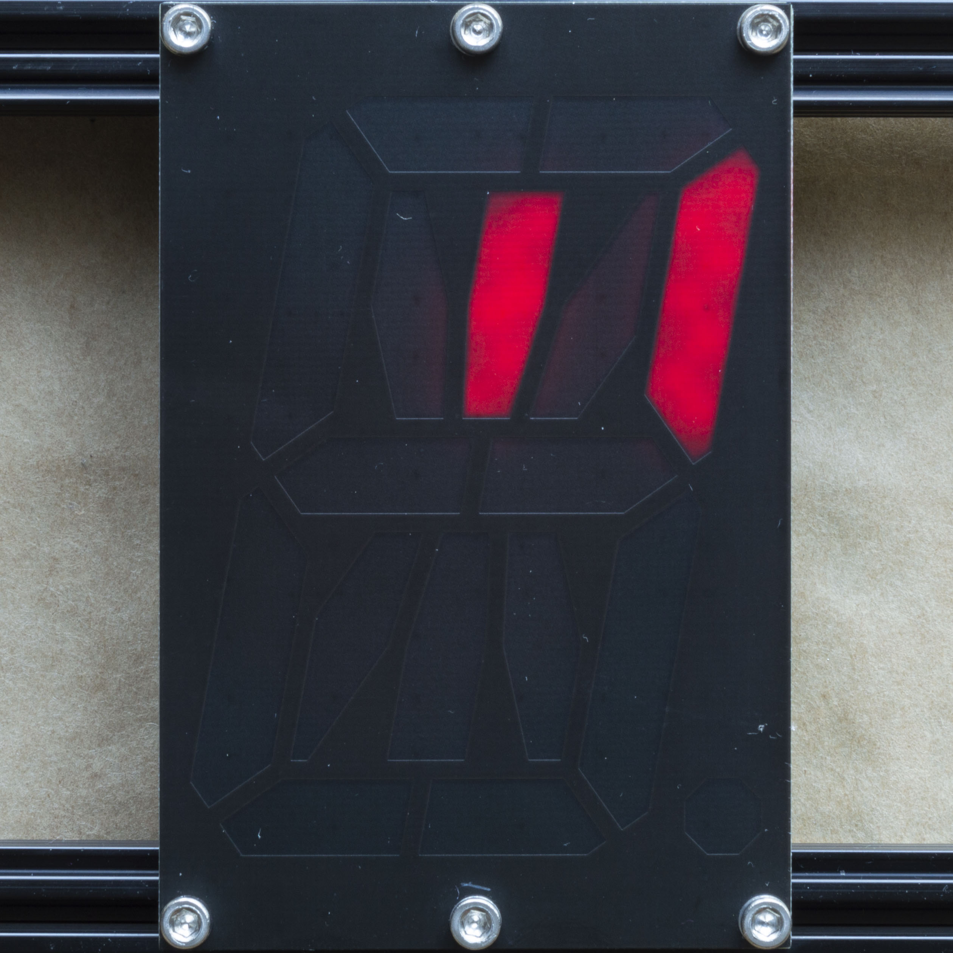
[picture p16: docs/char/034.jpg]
| 34 | `"` |   | 50.3 | 46.4 | 43.2 | 39.7 | 37.2 | 18.0 | | |
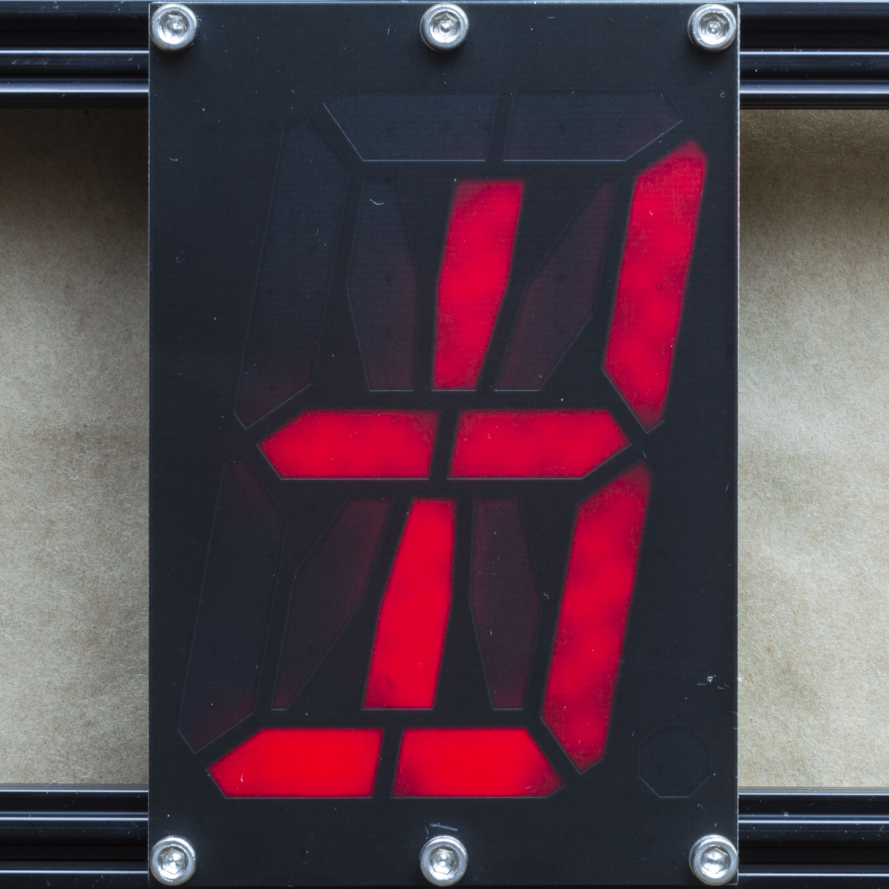
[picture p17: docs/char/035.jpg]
| 35 | `#` |   | 175.5 | 160.7 | 147.8 | 136.0 | 125.1 | 54.5 | | |
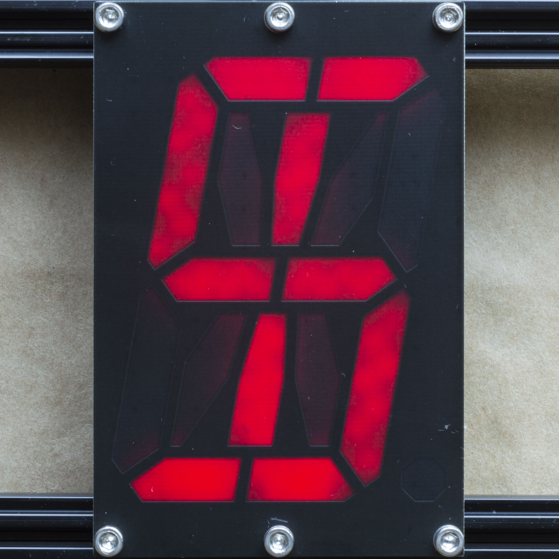
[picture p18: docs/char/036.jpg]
| 36 | `$` |   | 213.5 | 195.6 | 180.0 | 165.6 | 152.3 | 66.1 | | |
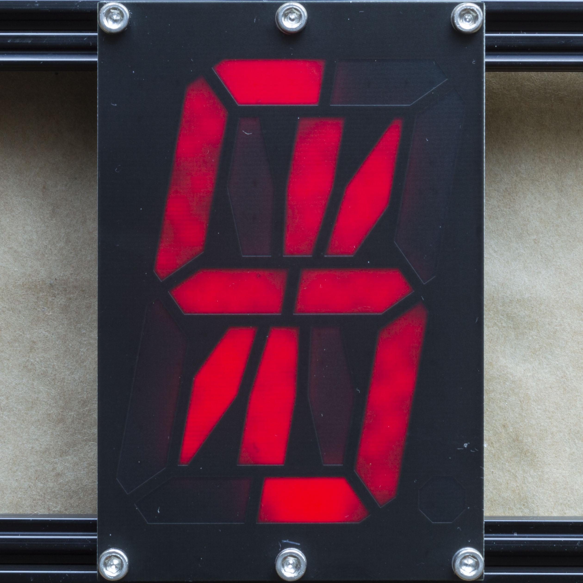
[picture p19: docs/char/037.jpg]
| 37 | `%` |   | 216.0 | 195.3 | 179.7 | 165.3 | 152.1 | 67.0 | | |
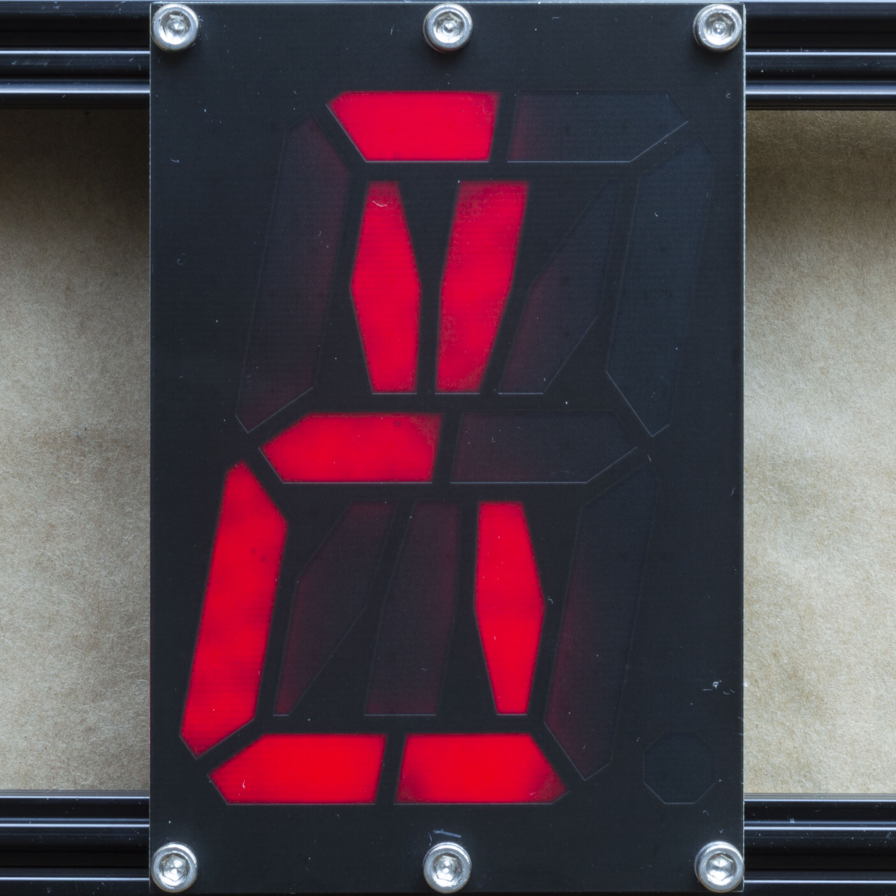
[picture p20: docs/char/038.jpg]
| 38 | `&` |   | 187.0 | 172.0 | 158.2 | 145.6 | 133.9 | 58.4 | | |
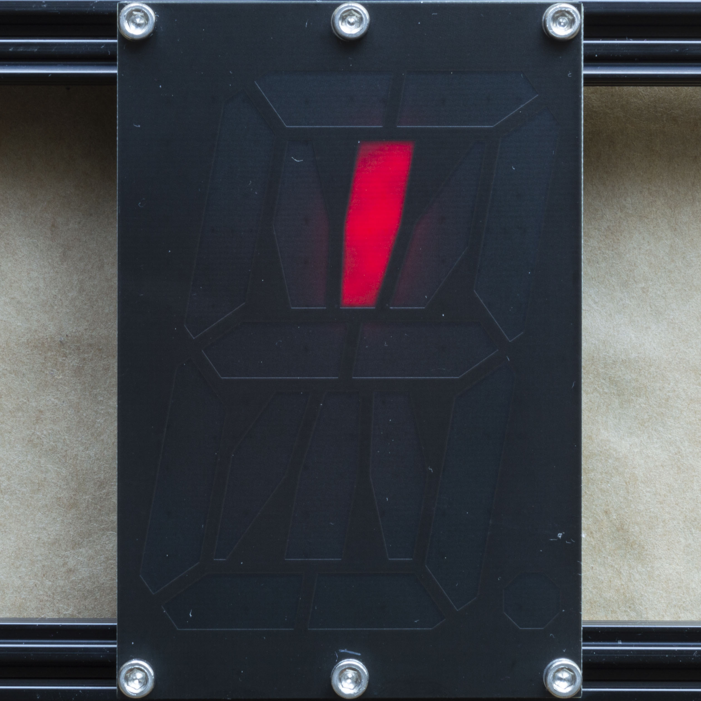
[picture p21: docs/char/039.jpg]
| 39 | `'` |   | 27.8 | 25.9 | 23.8 | 21.9 | 20.2 | 11.6 | | |
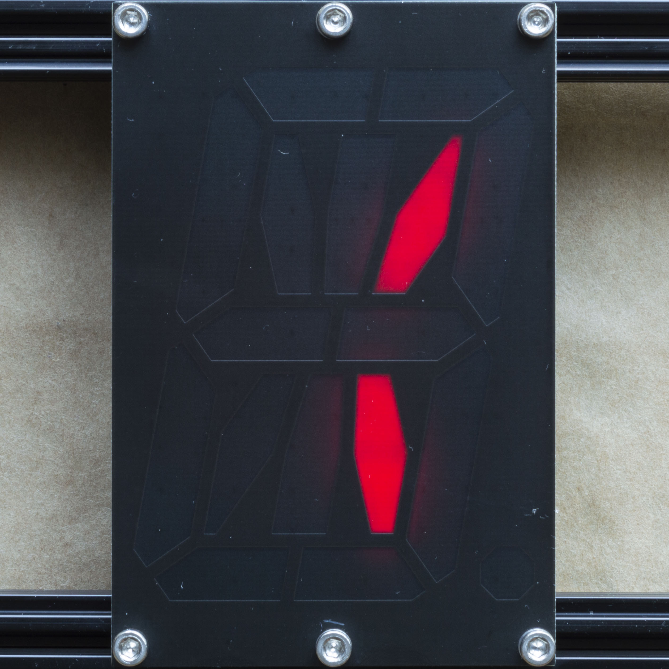
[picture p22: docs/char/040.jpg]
| 40 | `(` |   | 62.1 | 57.4 | 52.8 | 48.6 | 44.7 | 21.5 | | |
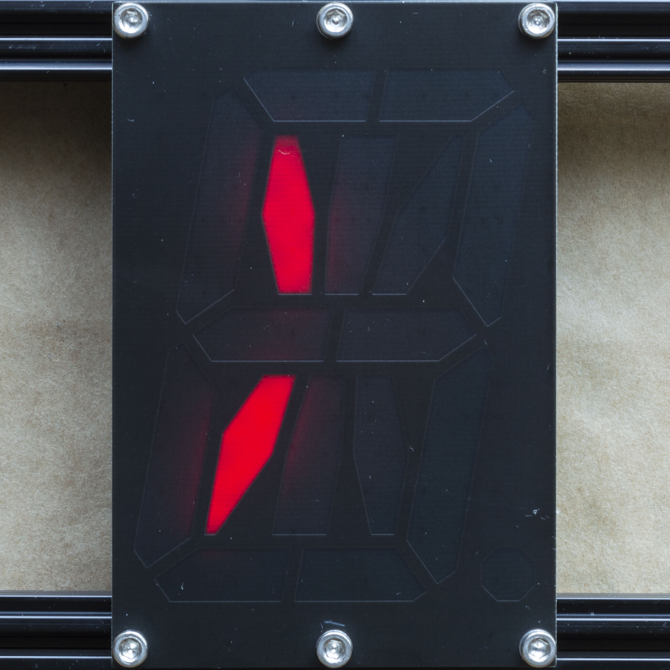
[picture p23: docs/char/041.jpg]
| 41 | `)` |   | 60.7 | 56.2 | 51.7 | 47.6 | 43.8 | 21.1 | | |
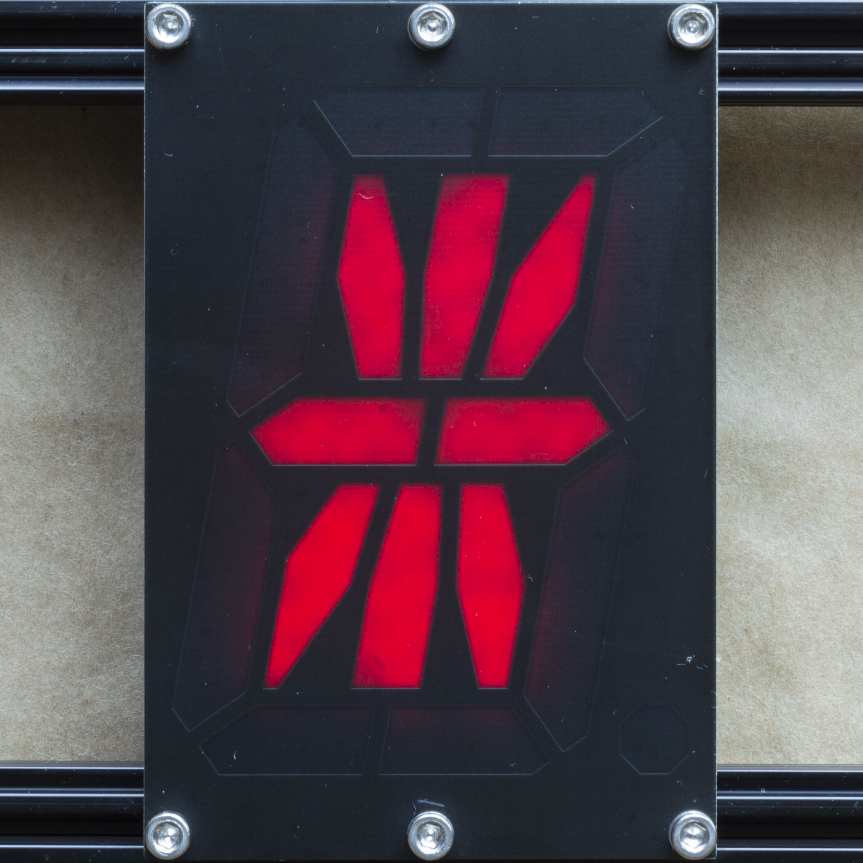
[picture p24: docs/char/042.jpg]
| 42 | `*` |   | 171.6 | 157.6 | 145.0 | 133.4 | 122.7 | 53.6 | | |
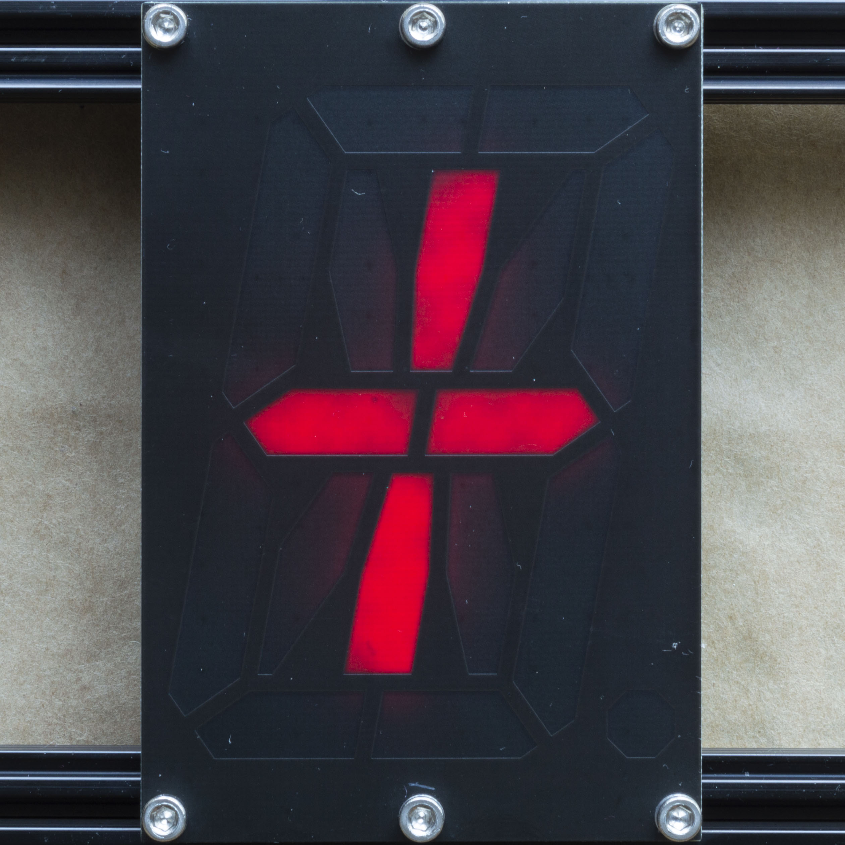
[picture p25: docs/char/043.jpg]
| 43 | `+` |   | 92.2 | 85.0 | 78.2 | 71.9 | 66.2 | 30.3 | | |
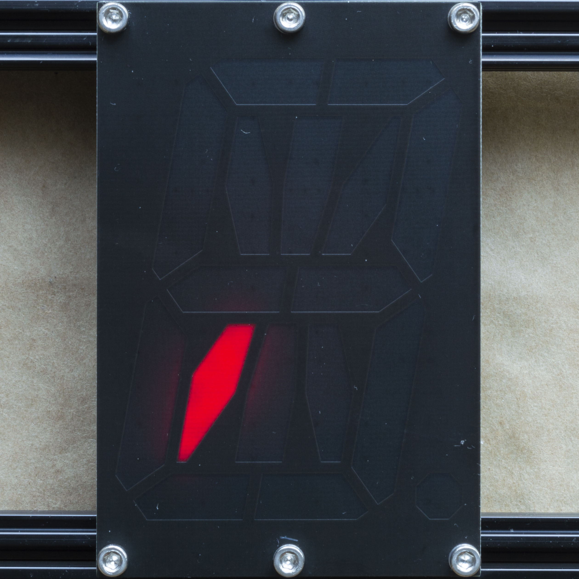
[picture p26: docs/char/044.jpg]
| 44 | `,` |   | 34.8 | 32.5 | 29.9 | 27.5 | 25.3 | 13.6 | | |
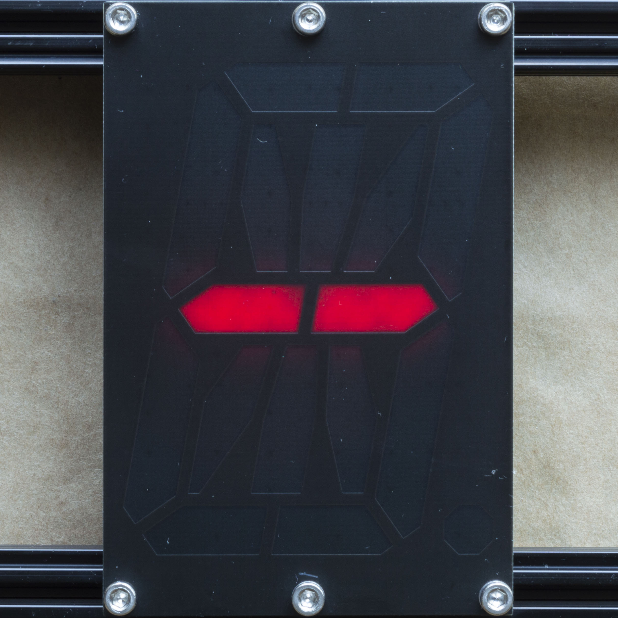
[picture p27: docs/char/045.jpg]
| 45 | `-` |   | 40.9 | 37.8 | 34.8 | 32.0 | 29.4 | 15.4 | | |
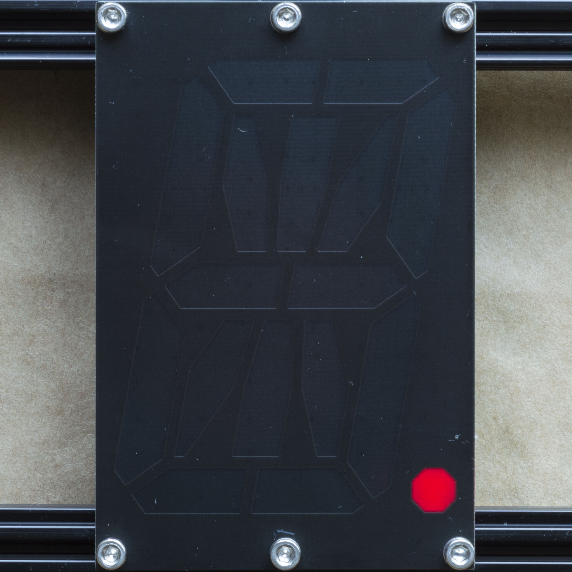
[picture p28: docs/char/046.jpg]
| 46 | `.` |   | 17.1 | 16.2 | 14.9 | 13.7 | 12.6 | 8.6 | | |
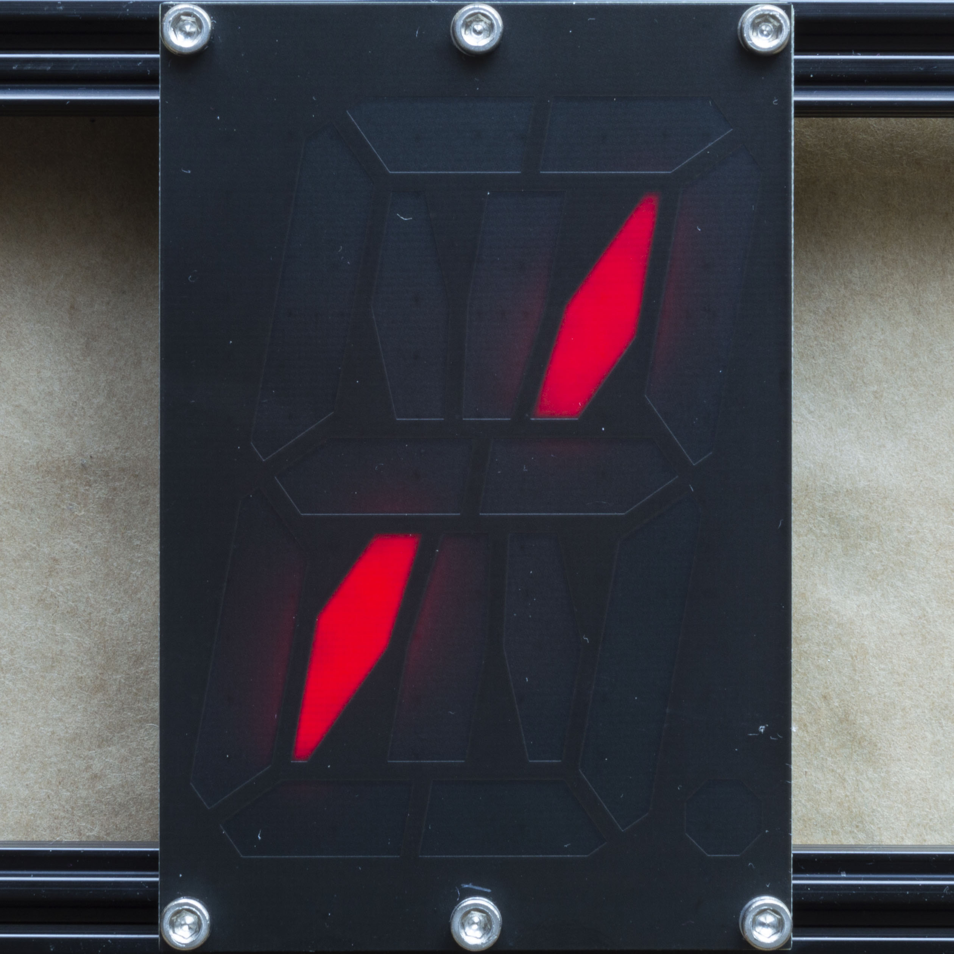
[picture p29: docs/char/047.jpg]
| 47 | `/` |   | 61.5 | 57.0 | 52.4 | 48.2 | 44.4 | 21.3 | | |
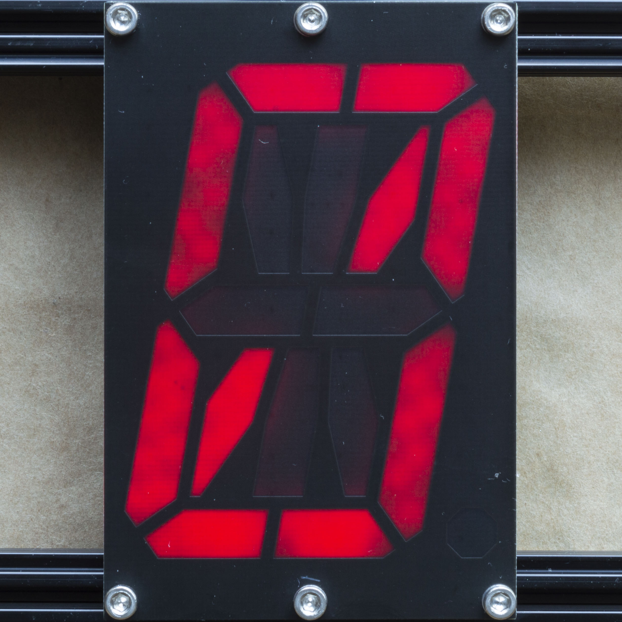
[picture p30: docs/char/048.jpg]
| 48 | `0` |   | 227.9 | 204.8 | 188.4 | 173.3 | 159.5 | 69.0 | | |
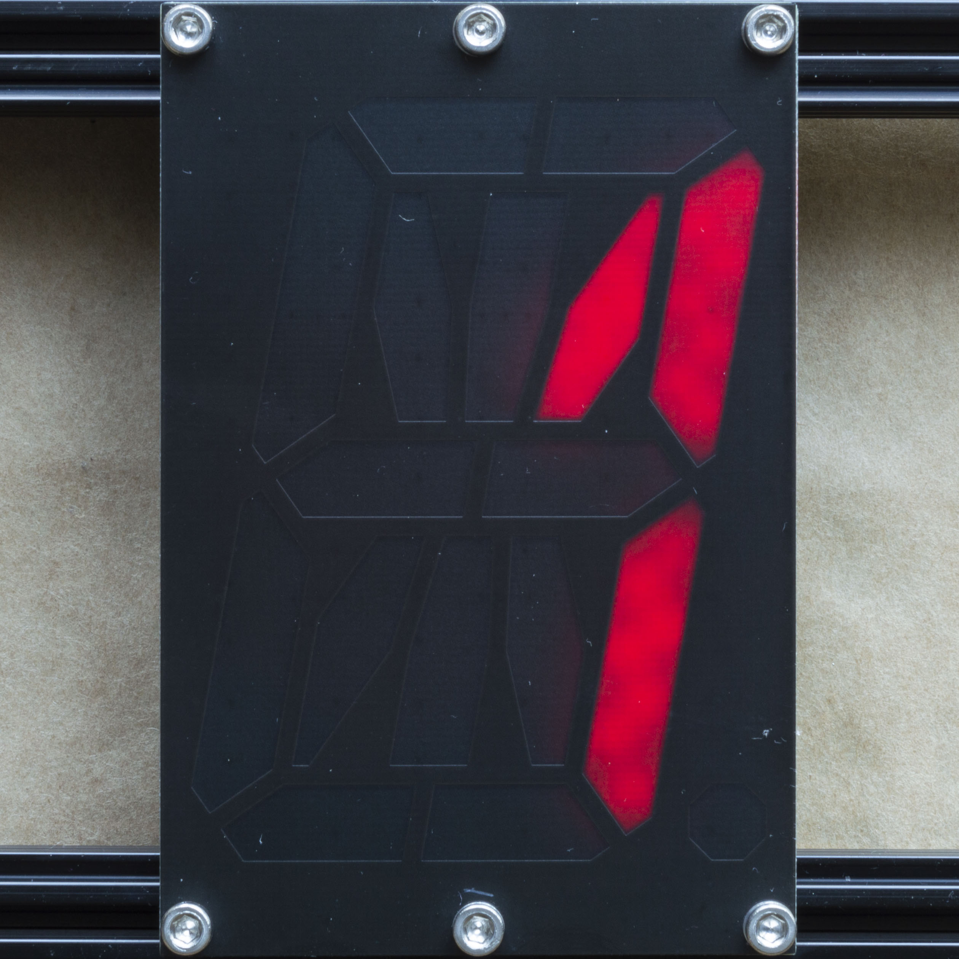
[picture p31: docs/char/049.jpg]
| 49 | `1` |   | 79.8 | 73.7 | 67.8 | 62.4 | 57.4 | 26.7 | | |
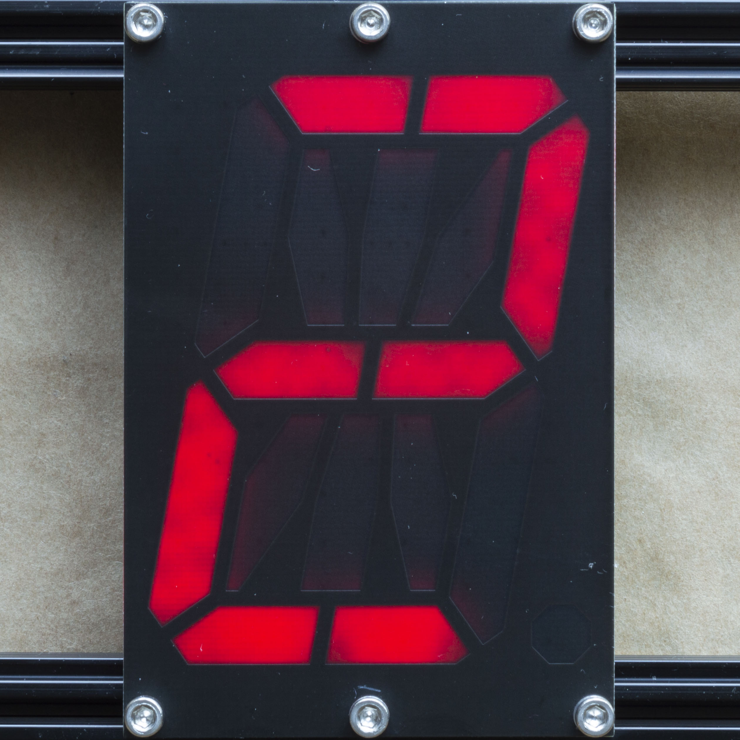
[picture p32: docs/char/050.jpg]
| 50 | `2` |   | 178.0 | 163.7 | 150.6 | 138.6 | 127.5 | 55.7 | | |
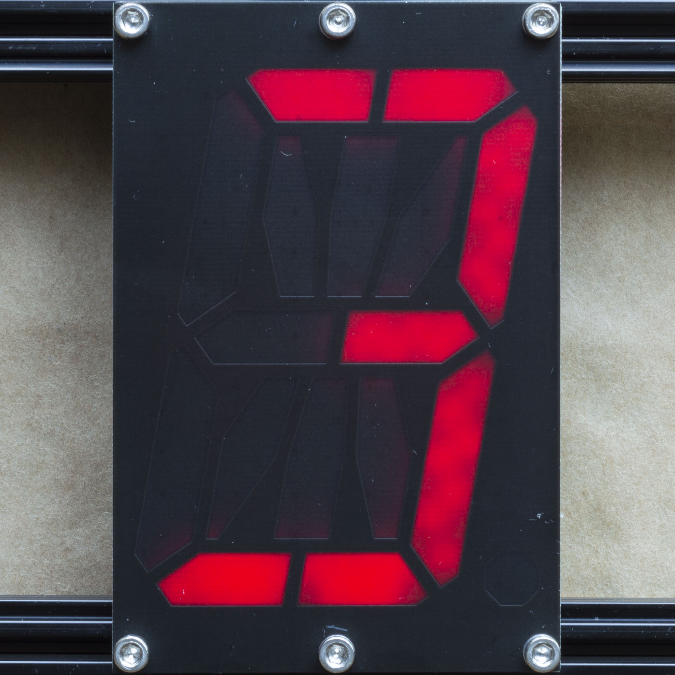
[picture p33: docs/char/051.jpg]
| 51 | `3` |   | 159.6 | 147.0 | 135.2 | 124.4 | 114.5 | 50.2 | | |
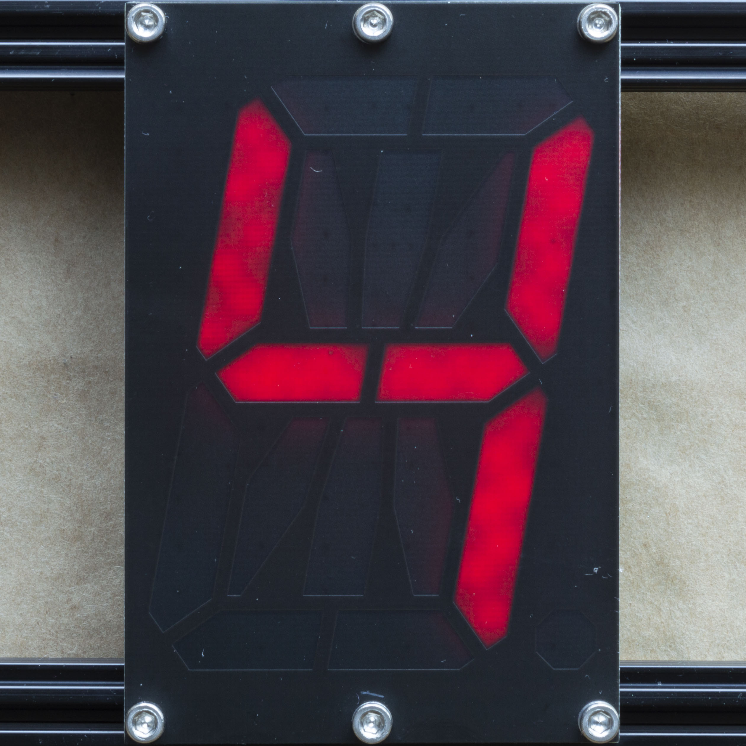
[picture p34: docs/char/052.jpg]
| 52 | `4` |   | 111.8 | 103.1 | 94.9 | 87.3 | 80.3 | 36.1 | | |
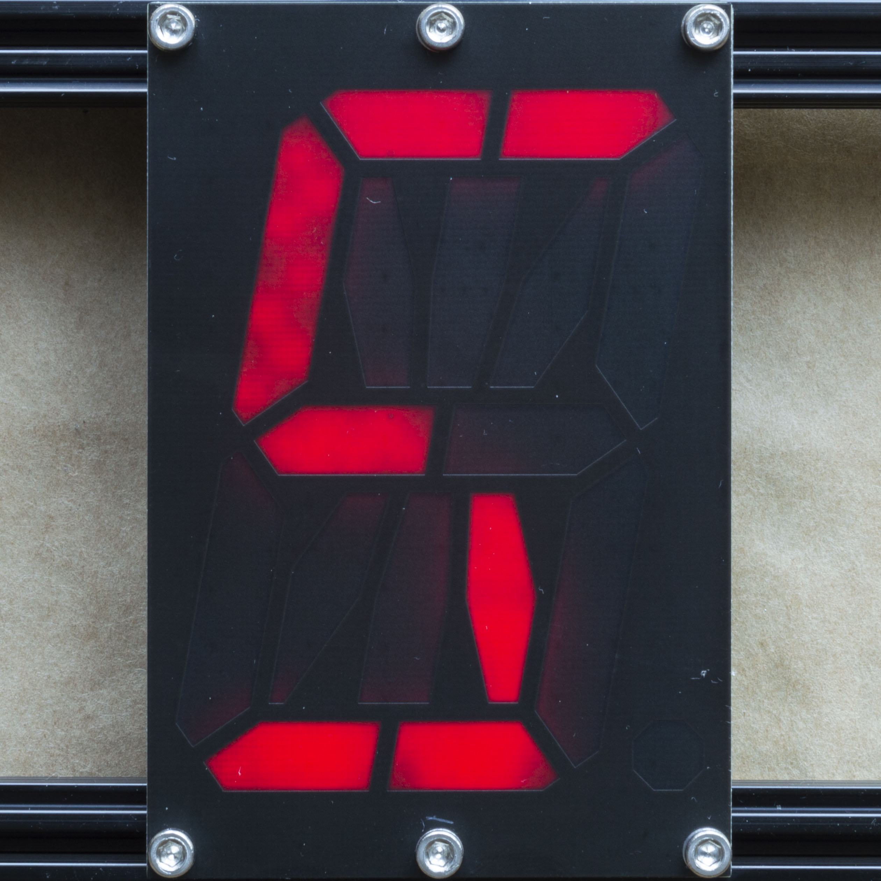
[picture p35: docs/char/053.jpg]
| 53 | `5` |   | 160.0 | 147.2 | 135.4 | 124.6 | 114.6 | 50.4 | | |
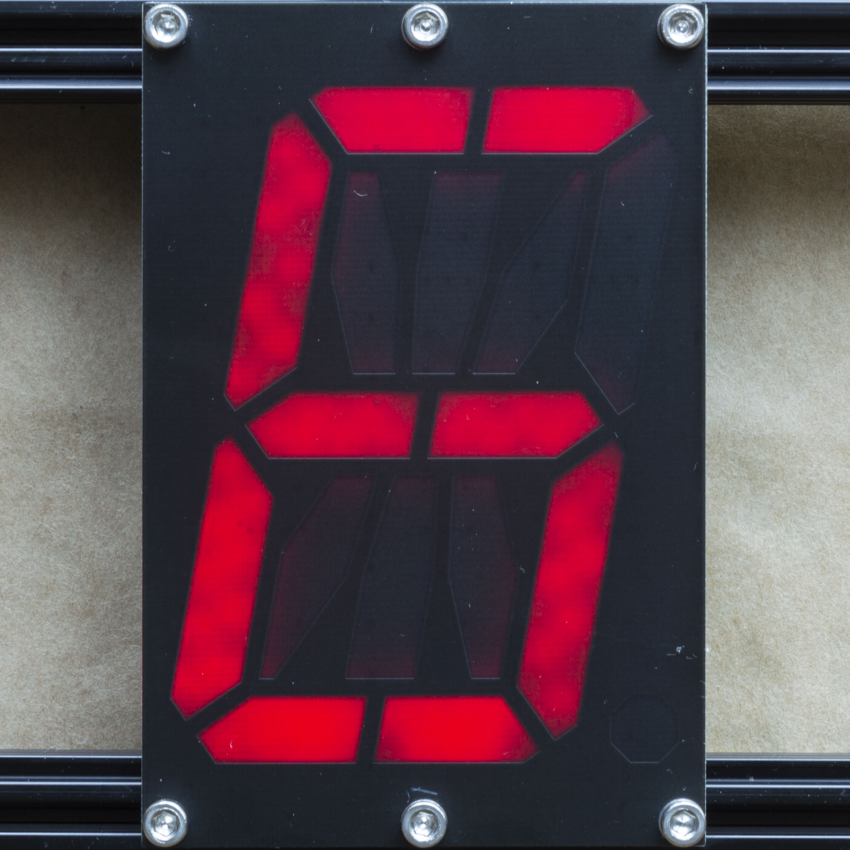
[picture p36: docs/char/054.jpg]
| 54 | `6` |   | 196.3 | 180.7 | 166.2 | 152.9 | 140.7 | 61.3 | | |
| 55 | `7` |   | 98.6 | 91.0 | 83.7 | 77.0 | 70.9 | 32.3 | | |
| 56 | `8` |   | 216.2 | 199.0 | 183.1 | 168.4 | 155.0 | 67.2 | | |
| 57 | `9` |   | 191.0 | 175.5 | 161.5 | 148.5 | 136.7 | 60.0 | | |
| 58 | `:` |   | 56.8 | 52.8 | 48.6 | 44.7 | 41.1 | 20.0 | | |
| 59 | `;` |   | 56.9 | 53.0 | 48.8 | 44.9 | 41.3 | 20.1 | | |
| 60 | `<` |   | 79.9 | 73.8 | 67.9 | 62.5 | 57.5 | 26.7 | | |
| 61 | `=` |   | 82.0 | 75.5 | 69.5 | 63.9 | 58.8 | 27.4 | | |
| 62 | `>` |   | 79.4 | 73.2 | 67.3 | 62.0 | 57.0 | 26.6 | | |
| 63 | `?` |   | 133.7 | 123.3 | 113.4 | 104.4 | 96.0 | 42.6 | | |
| 64 | `@` |   | 197.0 | 181.4 | 166.9 | 153.5 | 141.3 | 61.5 | | |
| 65 | `A` |   | 178.0 | 163.8 | 150.7 | 138.6 | 127.5 | 55.8 | | |
| 66 | `B` |   | 199.6 | 183.8 | 169.1 | 155.6 | 143.1 | 62.4 | | |
| 67 | `C` |   | 141.5 | 130.3 | 119.9 | 110.3 | 101.5 | 45.0 | | |
| 68 | `D` |   | 179.0 | 164.7 | 151.5 | 139.4 | 128.2 | 56.2 | | |
| 69 | `E` |   | 160.3 | 149.0 | 137.1 | 126.1 | 116.0 | 50.6 | | |
| 70 | `F` |   | 121.6 | 112.3 | 103.3 | 95.1 | 87.4 | 39.2 | | |
| 71 | `G` |   | 182.2 | 167.9 | 154.5 | 142.1 | 130.7 | 57.1 | | |
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
|        127 | (del)   |   |      5.2 |      5.2 |      5.2 |      5.2 |      5.2 |      5.2 |      5.2 |      5.2 |

<!-- Test Stand -->
[currTest]: ./firmware/currentTestStand.jpg

<!-- Charachters -->
[032]: ./char/032.jpg 
[033]: ./char/033.jpg 
[034]: ./char/034.jpg 
[035]: ./char/035.jpg 
[036]: ./char/036.jpg 
[037]: ./char/037.jpg 
[038]: ./char/038.jpg 
[039]: ./char/039.jpg 
[040]: ./char/040.jpg 
[041]: ./char/041.jpg 
[042]: ./char/042.jpg 
[043]: ./char/043.jpg 
[044]: ./char/044.jpg 
[045]: ./char/045.jpg
[046]: ./char/046.jpg
[047]: ./char/047.jpg
[048]: ./char/048.jpg
[049]: ./char/049.jpg
[050]: ./char/050.jpg
[051]: ./char/051.jpg
[052]: ./char/052.jpg
[053]: ./char/053.jpg
[054]: ./char/054.jpg
[055]: ./char/055.jpg
[056]: ./char/056.jpg
[057]: ./char/057.jpg
[058]: ./char/058.jpg
[059]: ./char/059.jpg
[060]: ./char/060.jpg
[061]: ./char/061.jpg
[062]: ./char/062.jpg
[063]: ./char/063.jpg
[064]: ./char/064.jpg
[065]: ./char/065.jpg
[066]: ./char/066.jpg
[067]: ./char/067.jpg
[068]: ./char/068.jpg
[069]: ./char/069.jpg
[070]: ./char/070.jpg
[071]: ./char/071.jpg
[072]: ./char/072.jpg
[073]: ./char/073.jpg
[074]: ./char/074.jpg
[075]: ./char/075.jpg
[076]: ./char/076.jpg
[077]: ./char/077.jpg
[078]: ./char/078.jpg
[079]: ./char/079.jpg
[080]: ./char/080.jpg
[081]: ./char/081.jpg
[082]: ./char/082.jpg
[083]: ./char/083.jpg
[084]: ./char/084.jpg
[085]: ./char/085.jpg
[086]: ./char/086.jpg
[087]: ./char/087.jpg
[088]: ./char/088.jpg
[089]: ./char/089.jpg
[090]: ./char/090.jpg
[091]: ./char/091.jpg
[092]: ./char/092.jpg
[093]: ./char/093.jpg
[094]: ./char/094.jpg
[095]: ./char/095.jpg
[096]: ./char/096.jpg
[097]: ./char/097.jpg
[098]: ./char/098.jpg
[099]: ./char/099.jpg
[100]: ./char/100.jpg
[101]: ./char/101.jpg
[102]: ./char/102.jpg
[103]: ./char/103.jpg
[104]: ./char/104.jpg
[105]: ./char/105.jpg
[106]: ./char/106.jpg
[107]: ./char/107.jpg
[108]: ./char/108.jpg
[109]: ./char/109.jpg
[110]: ./char/110.jpg
[111]: ./char/111.jpg
[112]: ./char/112.jpg
[113]: ./char/113.jpg
[114]: ./char/114.jpg
[115]: ./char/115.jpg
[116]: ./char/116.jpg
[117]: ./char/117.jpg
[118]: ./char/118.jpg
[119]: ./char/119.jpg
[120]: ./char/120.jpg
[121]: ./char/121.jpg
[122]: ./char/122.jpg
[123]: ./char/123.jpg
[124]: ./char/124.jpg
[125]: ./char/125.jpg
[126]: ./char/126.jpg
[127]: ./char/127.jpg

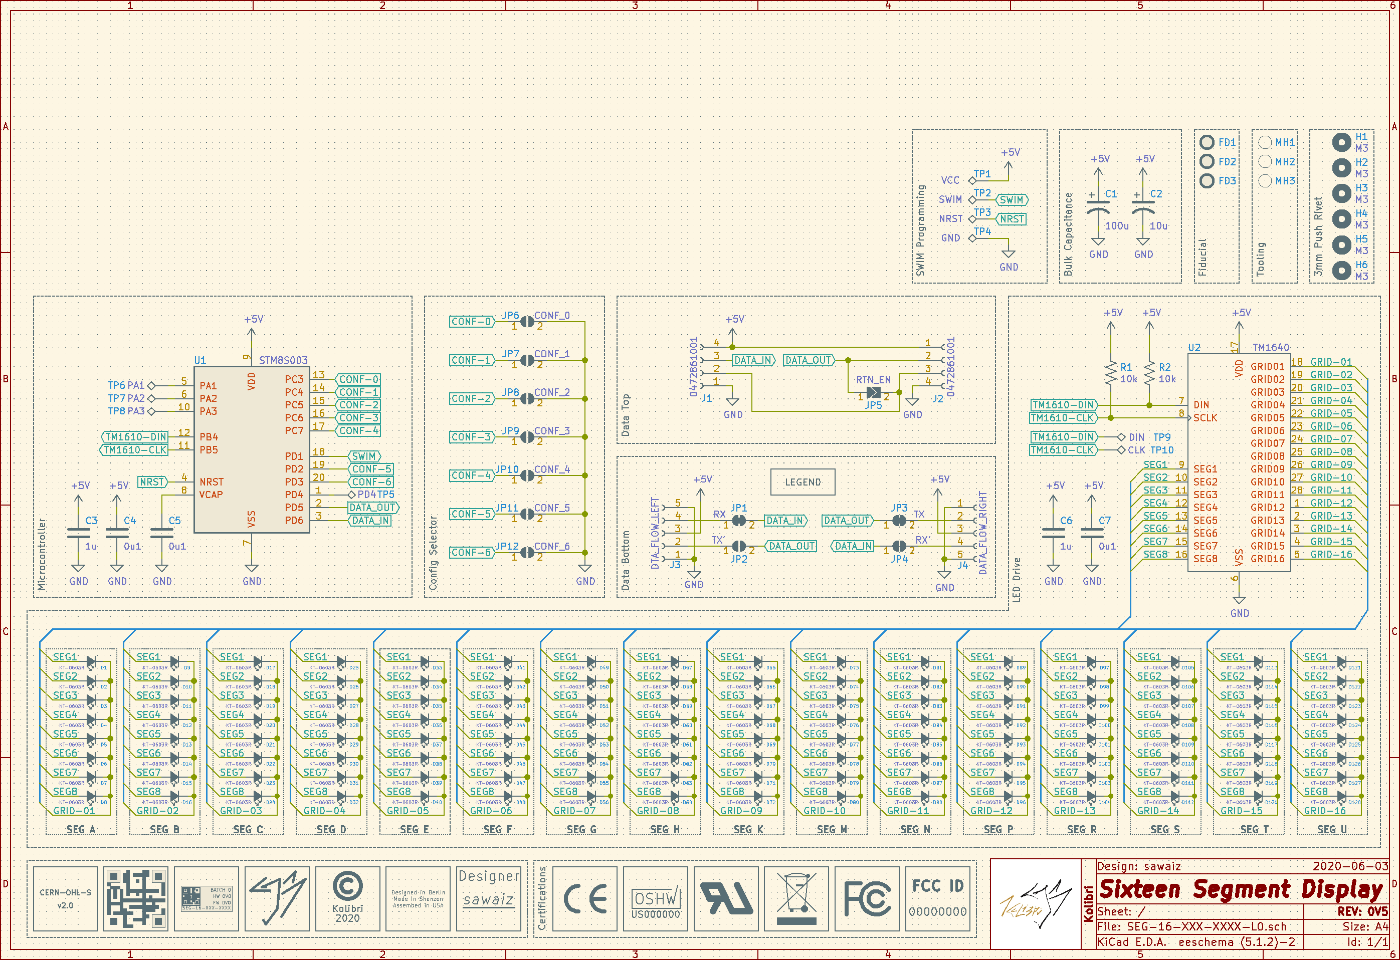
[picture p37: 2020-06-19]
docs/assembly/schematic.png

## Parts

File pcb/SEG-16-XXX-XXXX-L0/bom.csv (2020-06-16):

REF | QTY | Manufacturer | MPN | Description | LCSC
D1-D128 | 128 | Hubei KENTO Elec | KT-0603R | LED: RED 520~625NM 90~100MCD@20MA 0603 | C2286
U1 | 1 | STMicroelectronics | STM8S003F3P6TR | MCU: 8b 16Mhz 8k Flash 128B EEPROM TSSOP-20 | C52717
U2 | 1 | Shenzhen Titan Micro Elec | TM1640 | DRV: 16x8 LED Driver SOP-28 | C41327
C1 | 1 | AVX | TAJB107K006RNJ | CAP: Tantalum 100uF 6.3V CASE-B_3528 | C16133
C2 | 1 | AVX | TAJA106K016RNJ | CAP: Tantalum 10uF 16V CASE-A_3216 | C7171
C3 C6 | 3 | Samsung Electro-Mechanics | CL05A105KA5NQNC | CAP: MLCC 1uF 25V 0402 | C52923
C4 C5 C7 | 2 | Samsung Electro-Mechanics | CL05B104KO5NNNC | CAP: MLCC 100nF 16V 0402 | C1525
R1 R2 | 2 | Uniroyal Elec | 0402WGF1002TCE | RES: 10K 1% 1/16W 0402 | C25744

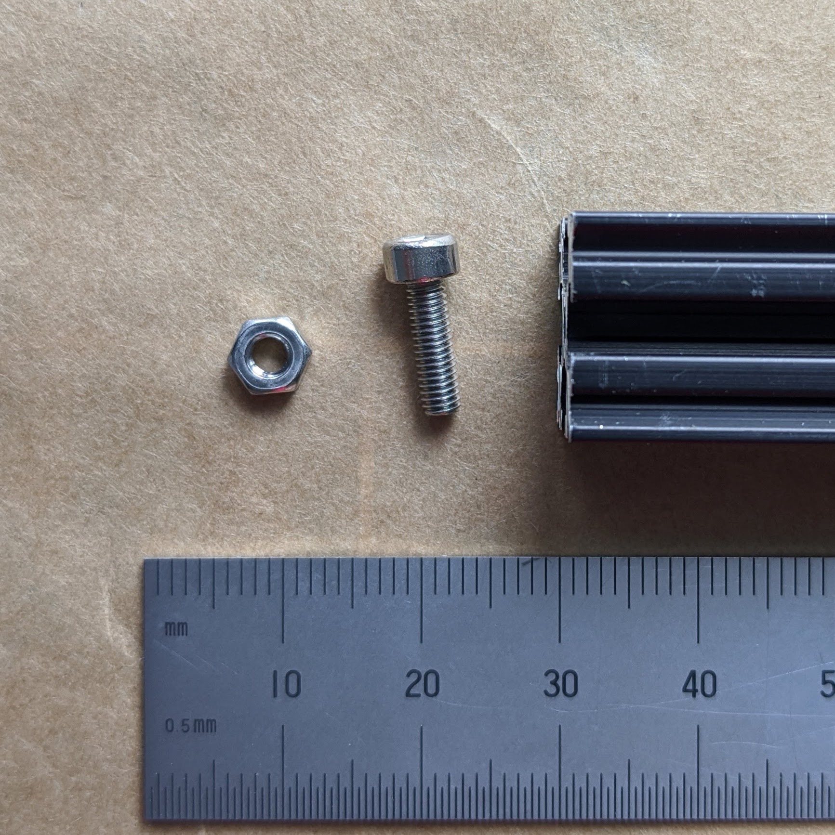
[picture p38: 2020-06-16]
docs/mounting/openbeamParts.jpg

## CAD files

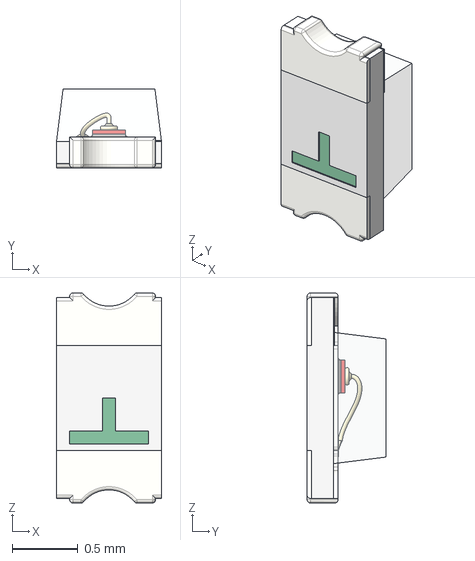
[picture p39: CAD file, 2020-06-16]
pcb/SEG-16-XXX-XXXX-L0/components/KT-0603R/KT-0603R.stp
0.8 x 0.6 x 1.60 mm

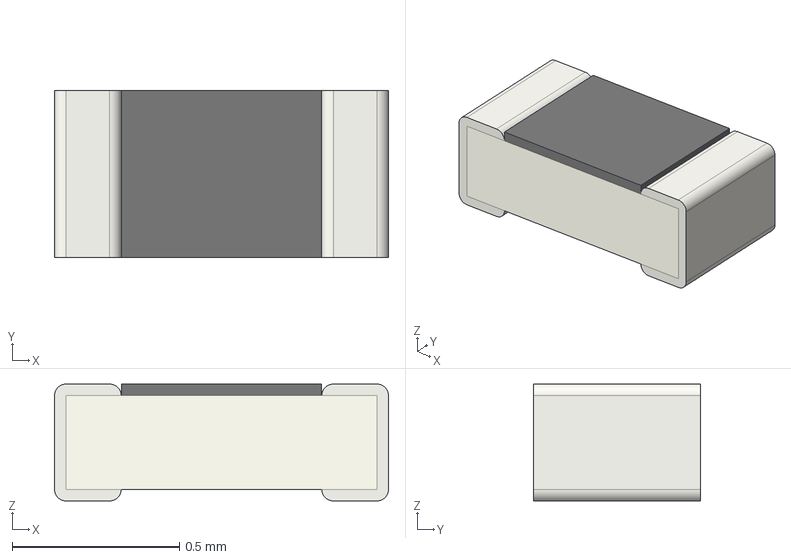
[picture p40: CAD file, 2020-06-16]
pcb/SEG-16-XXX-XXXX-L0/components/passives/R_0402.step
1.00 x 0.5 x 0.35 mm

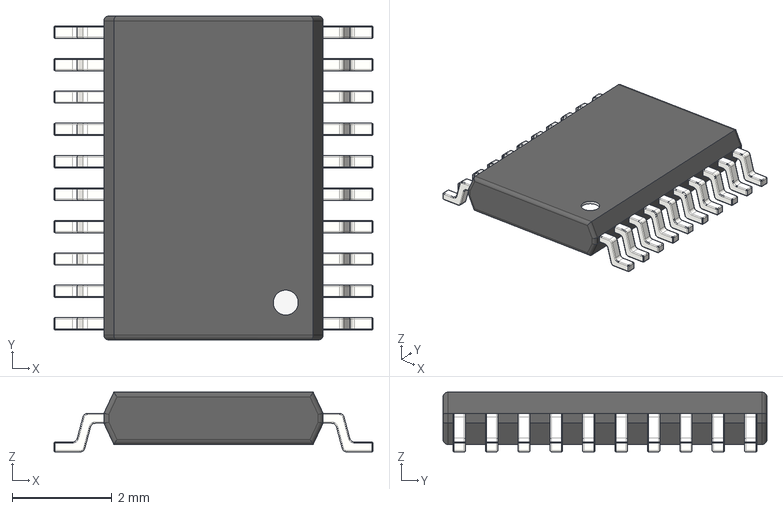
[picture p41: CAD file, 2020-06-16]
pcb/SEG-16-XXX-XXXX-L0/components/STM8S003/TSSOP20-6.5x6.4mm.stp
6.40 x 6.50 x 1.20 mm

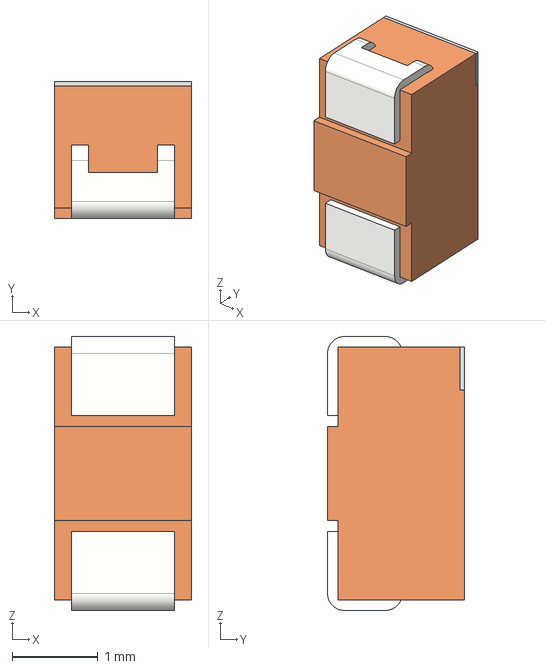
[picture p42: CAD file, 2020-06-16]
pcb/SEG-16-XXX-XXXX-L0/components/TAJA106K016RNJ/TAJA.stp
1.60 x 1.60 x 3.20 mm

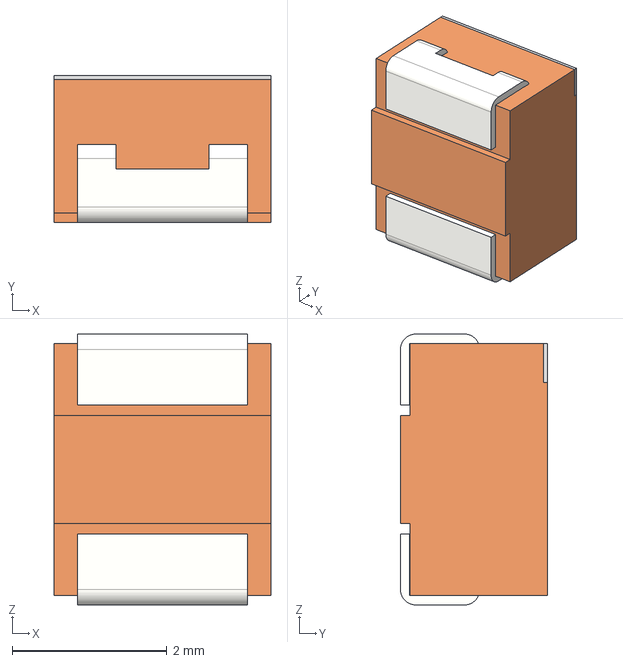
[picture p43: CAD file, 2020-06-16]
pcb/SEG-16-XXX-XXXX-L0/components/TAJB107K006RNJ/TAJB.stp
2.80 x 1.90 x 3.50 mm

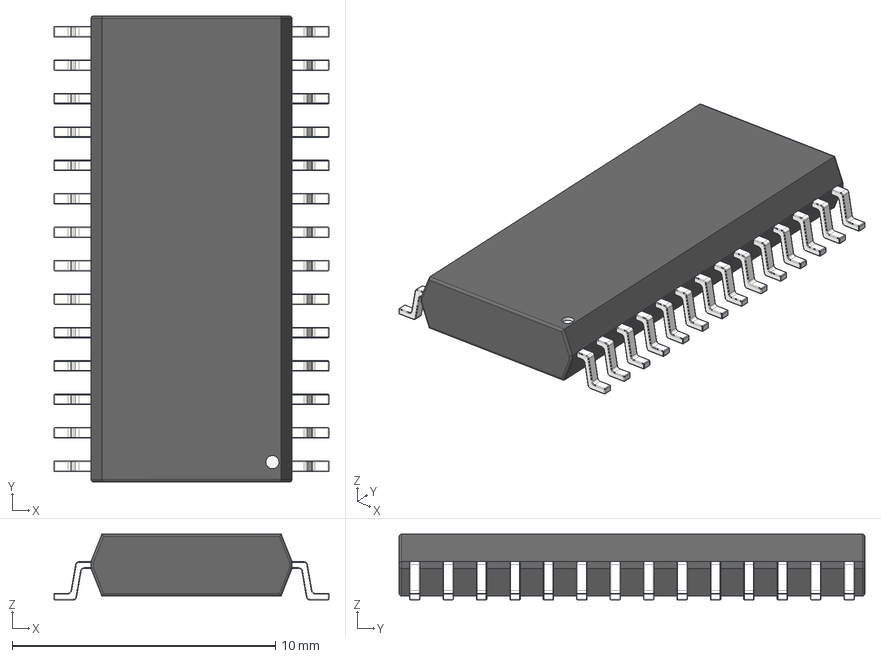
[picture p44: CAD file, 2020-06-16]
pcb/SEG-16-XXX-XXXX-L0/components/TM1640/SOP28.stp
10.4 x 17.7 x 2.50 mm

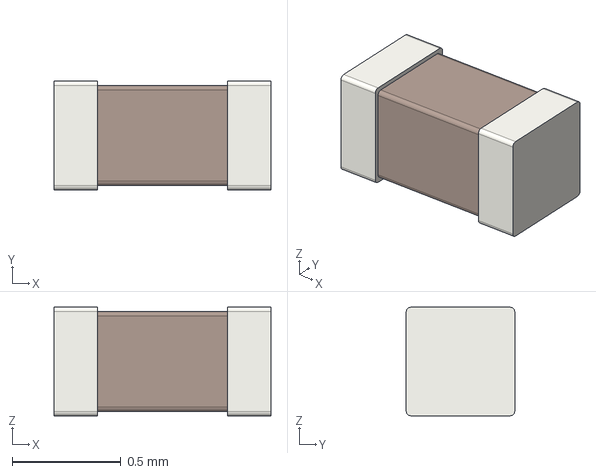
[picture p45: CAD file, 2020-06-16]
pcb/SEG-16-XXX-XXXX-L0/components/passives/C_0402.step
1.00 x 0.5 x 0.5 mm

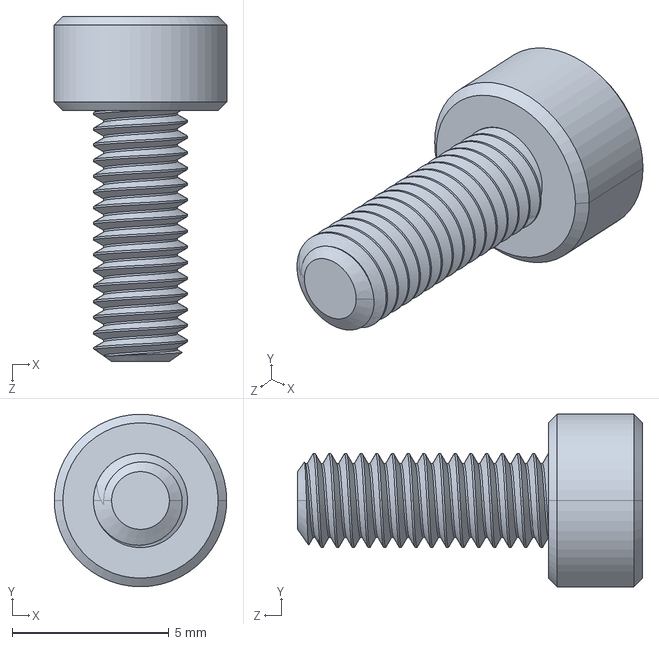
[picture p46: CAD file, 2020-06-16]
pcb/SEG-16-XXX-MDNT-L3/components/M3/M3x8-SS-SocketHead.stp
5.50 x 5.50 x 11.0 mm

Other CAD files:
pcb/SEG-16-XXX-XXXX-L0/components/0472861001/0472861001.stp

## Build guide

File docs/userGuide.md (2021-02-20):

# Sixteen Segment Display User Guide
This guide goes over basic usage instructions on how to implement the display into what you are making, a far more detailed [technical manual][readme] is also available. With examples for control with a few systems and languages.

Make sure you discharge any static electricity on a ground point before working on or assembling any displays.

## Contents
In the package you will recieve a labelled, programed, and tested display module in its default conifguration. Assembled with `3 mm` x `7.5 mm` plastic push rivets. All the components that make a module is pictured.

![contents]

## Required Tools
Only a few tools are required just some soldering and a way to mount your panels, get creative.

### Soldering Iron
You will need to do some really minimal soldering that is very forgiving. I am currenty using my portable TS100 soldering iron set at `350°C` (`650°F`). 

Along with the soldering iron you will need solder, I prefer rosin core leaded solder (Kester 60/40) which is easier to work with, but lead-free should be completely serviceable (you might need to bump up the temperature to `400°C`, `750°F`, for lead-free). Separate flux is also helpful to have, but probably not needed.

All components and the assembly are RHOS certified and a full lead-free process is used. If you are using leaded solder, you might need to dilute the lead-free solder with leaded for better wetting when soldering.

![toolsAndParts]

If you are mounting on aluminum extrusion, you will need allen keys or screwdrivers for the screws you are using (I use `2.5 mm` Boondus balldriver for M3 socket cap screws). Alternatively if mounting to wood with `#4` screws you will need a drill/driver, a pilot hole drill bit, and possibly a spade bit to make clearence for the joints.

## Mounting Method
There are quite a few mounting methods but I will go over a few of my favorites, depending on the look you want. 

### Canvas frame
Using canvas strechers to make a square frame, or even just wooden 1x2 that have been planed with `#4` or `3 mm` pan head wood screws is a quick assembly process. Drill pilot holes for mounting before driving in the screws, as the chance of splitting is high with thin pieces. If you use a whole backing board, you will need to drill clearance holes for the connections in the back.

### 15 mm Aluminum Extrusion
Aluminum extrusion like Misumi 1515 or OpenBeam is easy to cut to length with a hacksaw, and can mount with M3 screws. No holes need to be drilled and at least two screws per module ensures everything is kept in square.



### 20 mm Aluminum Extrusion
The panels, if joined together with pins for alignment, can be slid into the slots in Misumi 2020 or 80/20 metric extrusion. They can be secured in place with slot covers or T-nuts with grub screws.

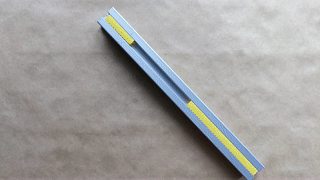
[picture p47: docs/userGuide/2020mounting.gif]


## Assemlbing a Array
After mounting the segments, the contacts are bridged for the data flow. Just add solder until it builds up to the point that it bridges over. You can also use a small piece of wire in place to make the solder bridge easier. The contacts are placed 0.1 in apart so header pins could also be used if bent into place.

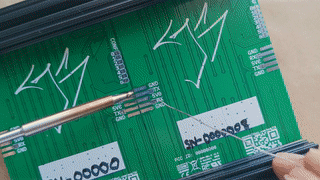
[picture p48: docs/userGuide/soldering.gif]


Then on the first panel connect in the data from the controller or computer as well as `+5V` and `GND` pins. Be wary of current requrements, exact numbers for each character and brightness vaules are available in a [table][currentTable], but each module can draw a max current of about `320 mA` so make sure your power supply is sufficently rated.



Remember the transmit of one module or the controller always goes to the recieve of the next. Its natural to think that the pins should be lined up same to same, but since serial data is unidrectional one device talks (`TX`) and the next one listens (`RX`). I can not count the number of times I've messed this up. You won't break anything, but things just won't work if you install a panel upside down.

If you want to use a baud rate other than 115200 bits per second, you can bridge the config pads to select one of the 15 alternative bitrates from the [configuration table].

## Disassembly
Reheat the solder joints with a clean tip to pick up some solder and unbridge the connection. If needed the pads can then be cleaned with an iron at `400°C` (`750°F`) and solder wick. 

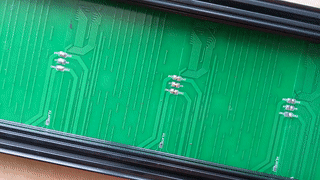
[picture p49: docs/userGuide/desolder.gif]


## Surface Repair
The surface coating of soldermask is fairly robust (TAIYO INK PSR-2000) but if scratches appear, black matte nail polish can be used to apply another coat as a close match.

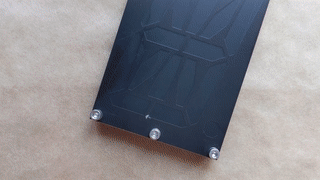
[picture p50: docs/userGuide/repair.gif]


## Writing
The data in the segments is shifted across when a new character is sent. In order to show characters in a left to right format, they will need to be sent in reverse. 

This can be done with built in tools like `rev` in linux, manually, by encoding the string backwards, or through looping the string in reverse and sending one character at a time. 

No custom libraries are needed for most platforms, as basic UART functionality already exits in hardware. This allows communication from a variety of machines from early home computers, microcontrollers, and laptops.

### Basic examples
Basic examples are provided for a number of diffrent languages and microcontroller environments for outputing a string to the display.

#### ✓ Windows Batch File
Run the following commands (directly in `cmd.exe` or in a `.bat` file) to set up COM** and output the string.
```cmd
mode COM** BAUD=115200 PARITY=n DATA=8
set /p x="olleh" <nul >\\.\COM**
```

#### ✓ Bash
Run the following commands (directly or in a `.sh` file). Outputs on /dev/sttyS***
```bash
stty -F /dev/ttyS*** 115200 cs8 -cstopb -parenb 
echo -ne "Hello" | rev > /dev/sttyS***
```

#### Node.js
Install the `serialport` dependency.
```bash
npm install --save serialport
```
Then directly in the interperter or in the `main.js` file.
```node
const SerialPort = require("serialport");
const port = new SerialPort(/dev/ttyS0, { baudRate: 115200 });
port.write("Hello".split("").reverse().join(""));
```

If in the `main.js` file, run it from the command line.
```bash
node ./main.js
```

#### ✓ Arduino
Minimal program for arduino.
```arduino
void setup(){
    Serial.begin(115200);
    Serial.print("olleH");
}
void loop(){

}
```

#### Micrpython/Circuitpython
In minimal program in `main.txt`.
```pyhton
import board
import busio
 
uart = busio.UART(board.TX, board.RX, baudrate=115200)
print("Hello"[::-1])
```

#### AVR (Attiny10)
```c

```

#### AVR ASM
```asm
```

#### Fortran
```fortran
    USE IFPORT
    SPORT_WRITE_DATA( 2, 'olleH', 5 )
    END
```

#### STM8S SPL
```c

```

<!-- Internal Links -->
[readme]:                    ../readme.md
[configuration table]:       ../readme.md#configuration
[currentTable]:              ./asciiCurrent.md

<!-- Images -->
[toolsAndParts]:             ./userGuide/toolsAndParts.jpg
[contents]:                  ./userGuide/contents.jpg

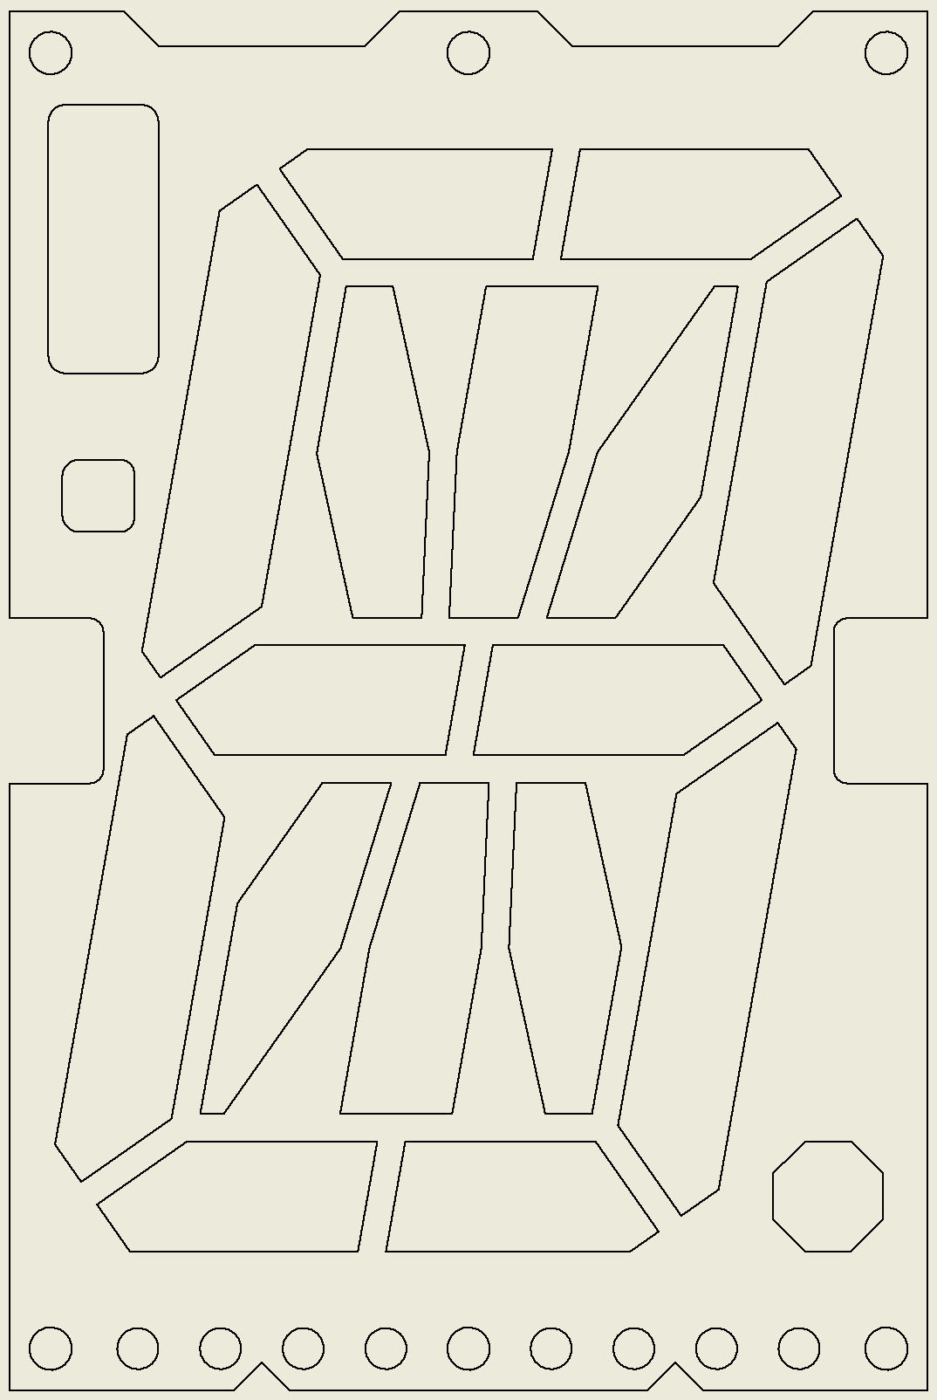
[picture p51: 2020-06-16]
docs/assembly/L2-DIE.png

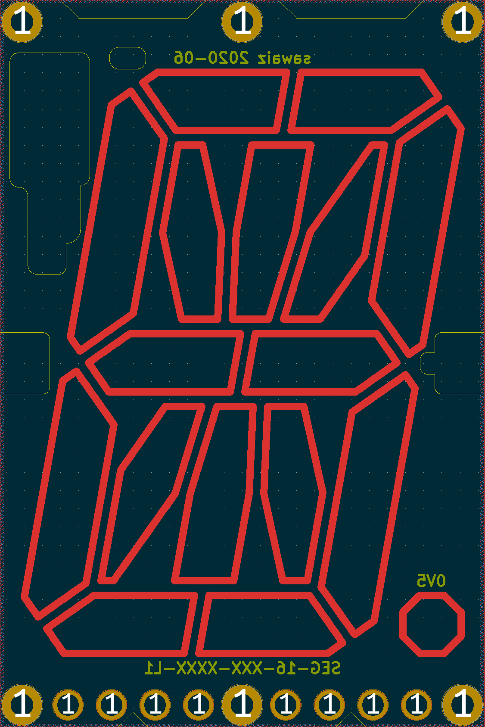
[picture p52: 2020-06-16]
docs/assembly/L1.png

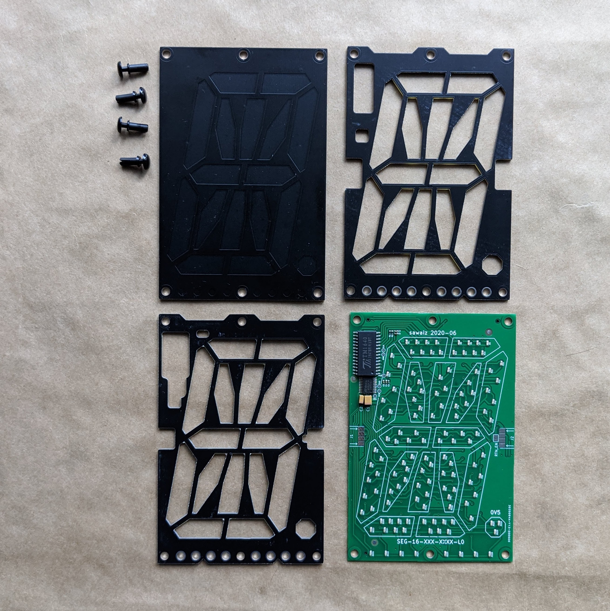
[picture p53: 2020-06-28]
docs/userGuide/contents.jpg

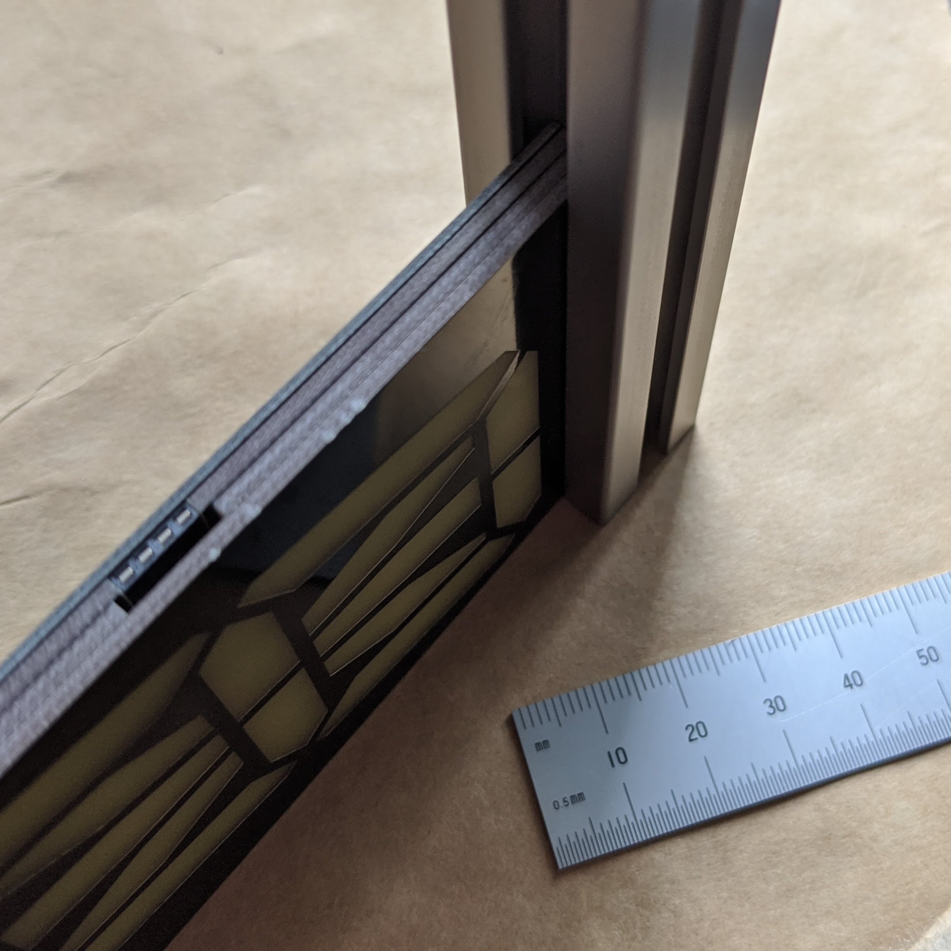
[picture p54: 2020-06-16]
docs/mounting/2020Installed.jpg

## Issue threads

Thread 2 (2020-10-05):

Display sometimes freezes after 6h+

Sawaiz, 2020-10-05:
I have noted that my array of displays intermittently a freeze, sometimes with a known character, and sometimes with random LEDs lit.

I haven to been able to reproduce it consistently, but if I leave my display running overnight about 60% of the time at least one character will be frozen. It seems to occur flowing from the far end of the array towards the signal source.

With the frozen module, any downstream modules will also not update.

It could be the HSI oscillator going out of sync due to temperate changes, but I would expect all the modules to change in sync.

Sawaiz, 2020-10-05:
A stopgap fix would be to implement a watchdog timer to see if that will reset as its possible that it is getting stuck in the UART interrupt routine. I have a test firmware with a 15ms watchdog set that I will program and see if that works for now.

Sawaiz, 2020-10-08:
Implemented the WDT and took some guessing on where to reset it, but I think I found someplace that works well. My guess is the actual issue is somewhere is the TX routine. Going to run a 48hr+ test before I bump up the FW version.

Sawaiz, 2020-10-16:
I ran a four day test, 250ms update for 13 panels, and it seems to be working fine now, Or at least recovering form any errors that occur. I'll push that to firmware v0.6.

Sawaiz, 2020-10-16:
Pushed in 2594056009b155e6c667d3915c9ad1faf220c8e1.

Closed 2020-10-16.

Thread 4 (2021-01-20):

Provide a 3D model of the "injection moulded panel"

DominikPalo, 2021-01-20:
I would like to try to 3D print the covering panel (using two colors - semitransparent and black), but I didn't find the 3D file in the repository (just the screenshot attached below). So, could you please share this design as a STEP or an STL file? Thank you! :)

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

Sawaiz, 2021-01-20:
Here ([imProto.zip](https://github.com/openKolibri/klais-16/files/5845870/imProto.zip)) is all the file types that could be useful that I can export. Its not included in the files until I design it in freecad or something that is acessible. I just sliced it and looks reasonable, but for printing you might want to remove a bunch of draft angles and the even wall thickness isn't as improtant.

Would love to see a photo of your print when you do it and to know how it works out!

DominikPalo, 2021-01-21:
Thank you - I imported the .igs file to my Fusion 360 and it works great, it seems I will bee able to adjust the model for better printing :) Of course, I will share the results with you, but I've just ordered the main PCB from JLPCB (and the TM1640 drivers from China), so it will take a few weeks until I finish and test it (it will be so much fun with those 128pcs of 0603 LEDs - I ordered stencils and will try to assemble it using a solder paste and hot air) :)

Anyway, thanks for the great and well-documented project - I like the idea!

Sawaiz, 2021-01-21:
Sounds great. The `.ipt` file would probably import best as that is the source and fusing is also autodesk.

Best of luck, you can reopen the issue if you have progress to share, or just tag `@openkolibri` and/or `@sawaizsyed` on twitter.

DominikPalo, 2021-01-21:
Yes, I know that `.ipt` would be better, but I'm using Fusion 360 with a free hobby license, which doesn't support importing IPT files (IPT files are supported only in paid license types).. therefore I used (but I will try to find someone who with a paid license who will convert that `.ipt` to `.f3d` so I can see the timeline and features from the original model)

Closed 2021-01-21.

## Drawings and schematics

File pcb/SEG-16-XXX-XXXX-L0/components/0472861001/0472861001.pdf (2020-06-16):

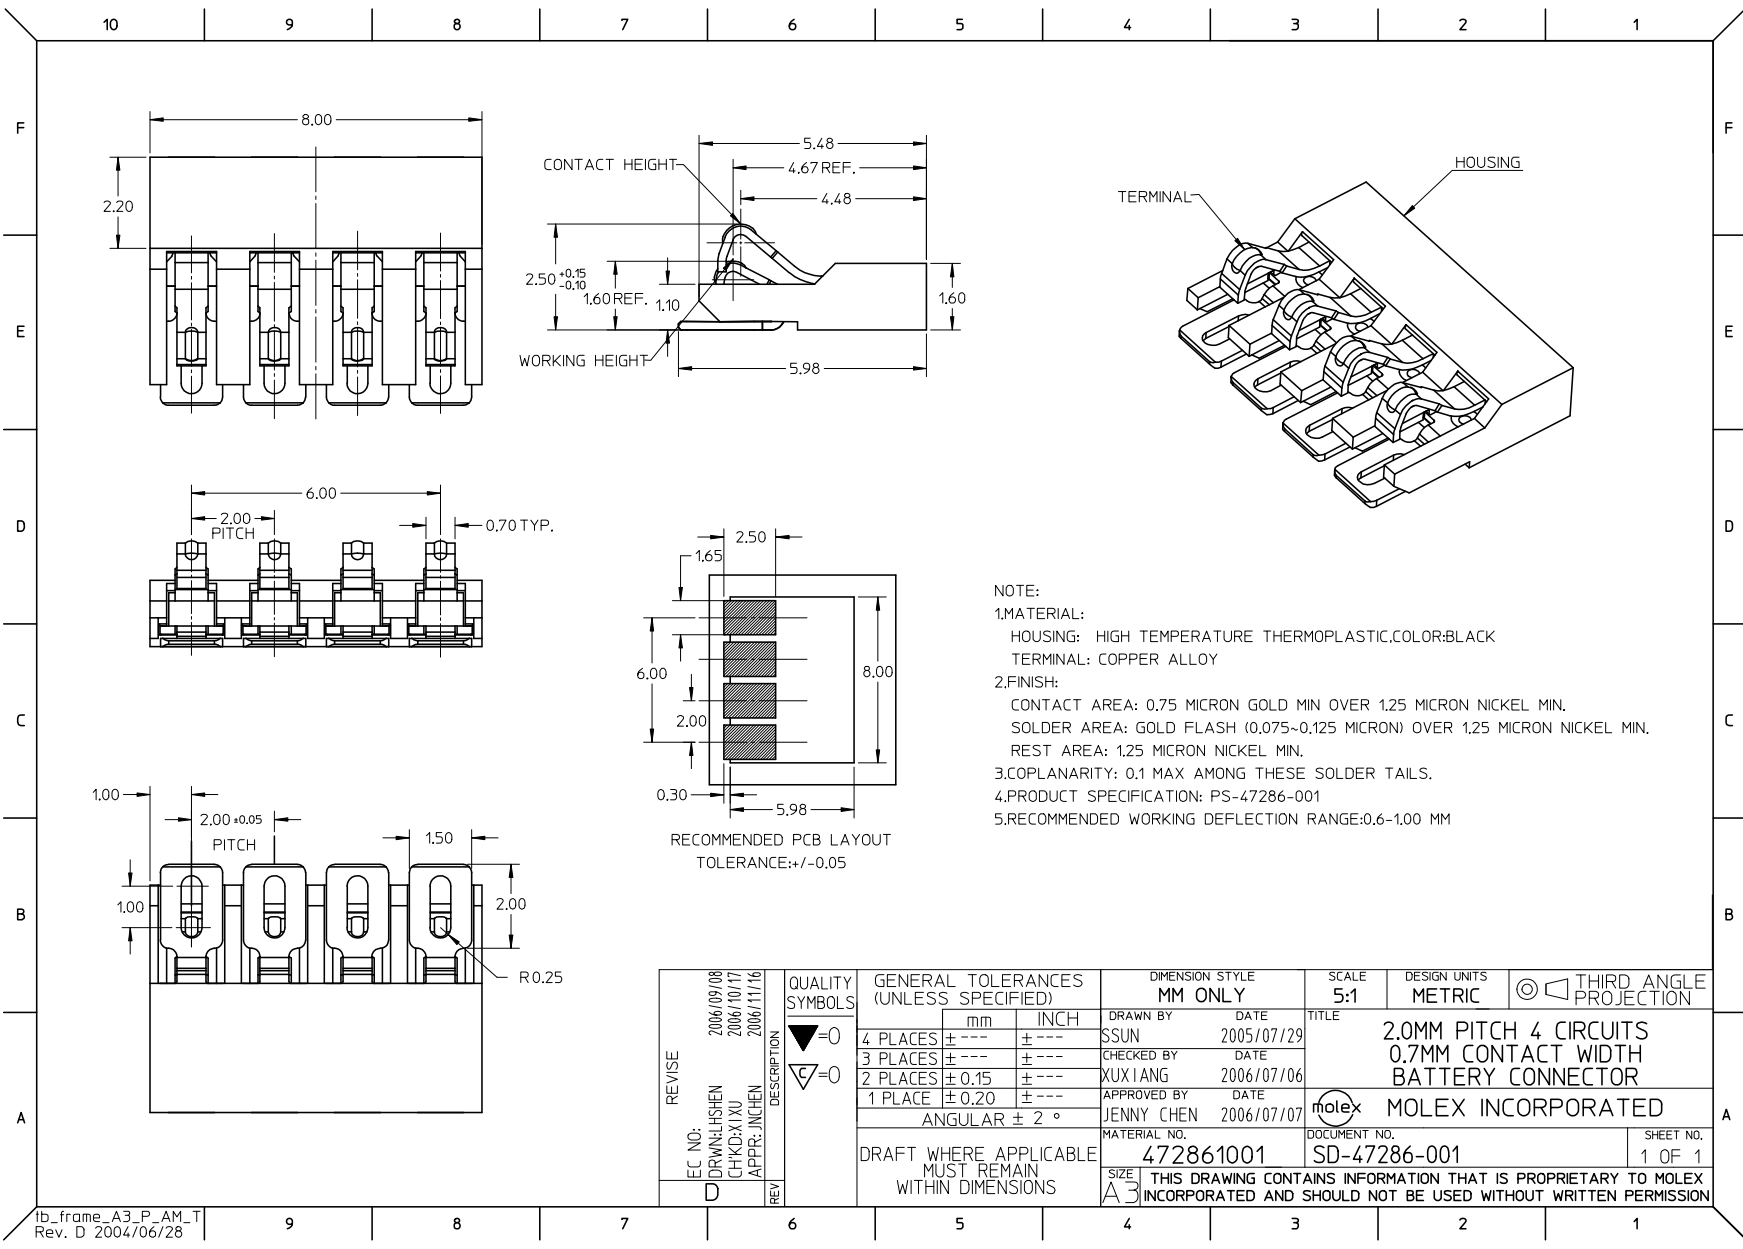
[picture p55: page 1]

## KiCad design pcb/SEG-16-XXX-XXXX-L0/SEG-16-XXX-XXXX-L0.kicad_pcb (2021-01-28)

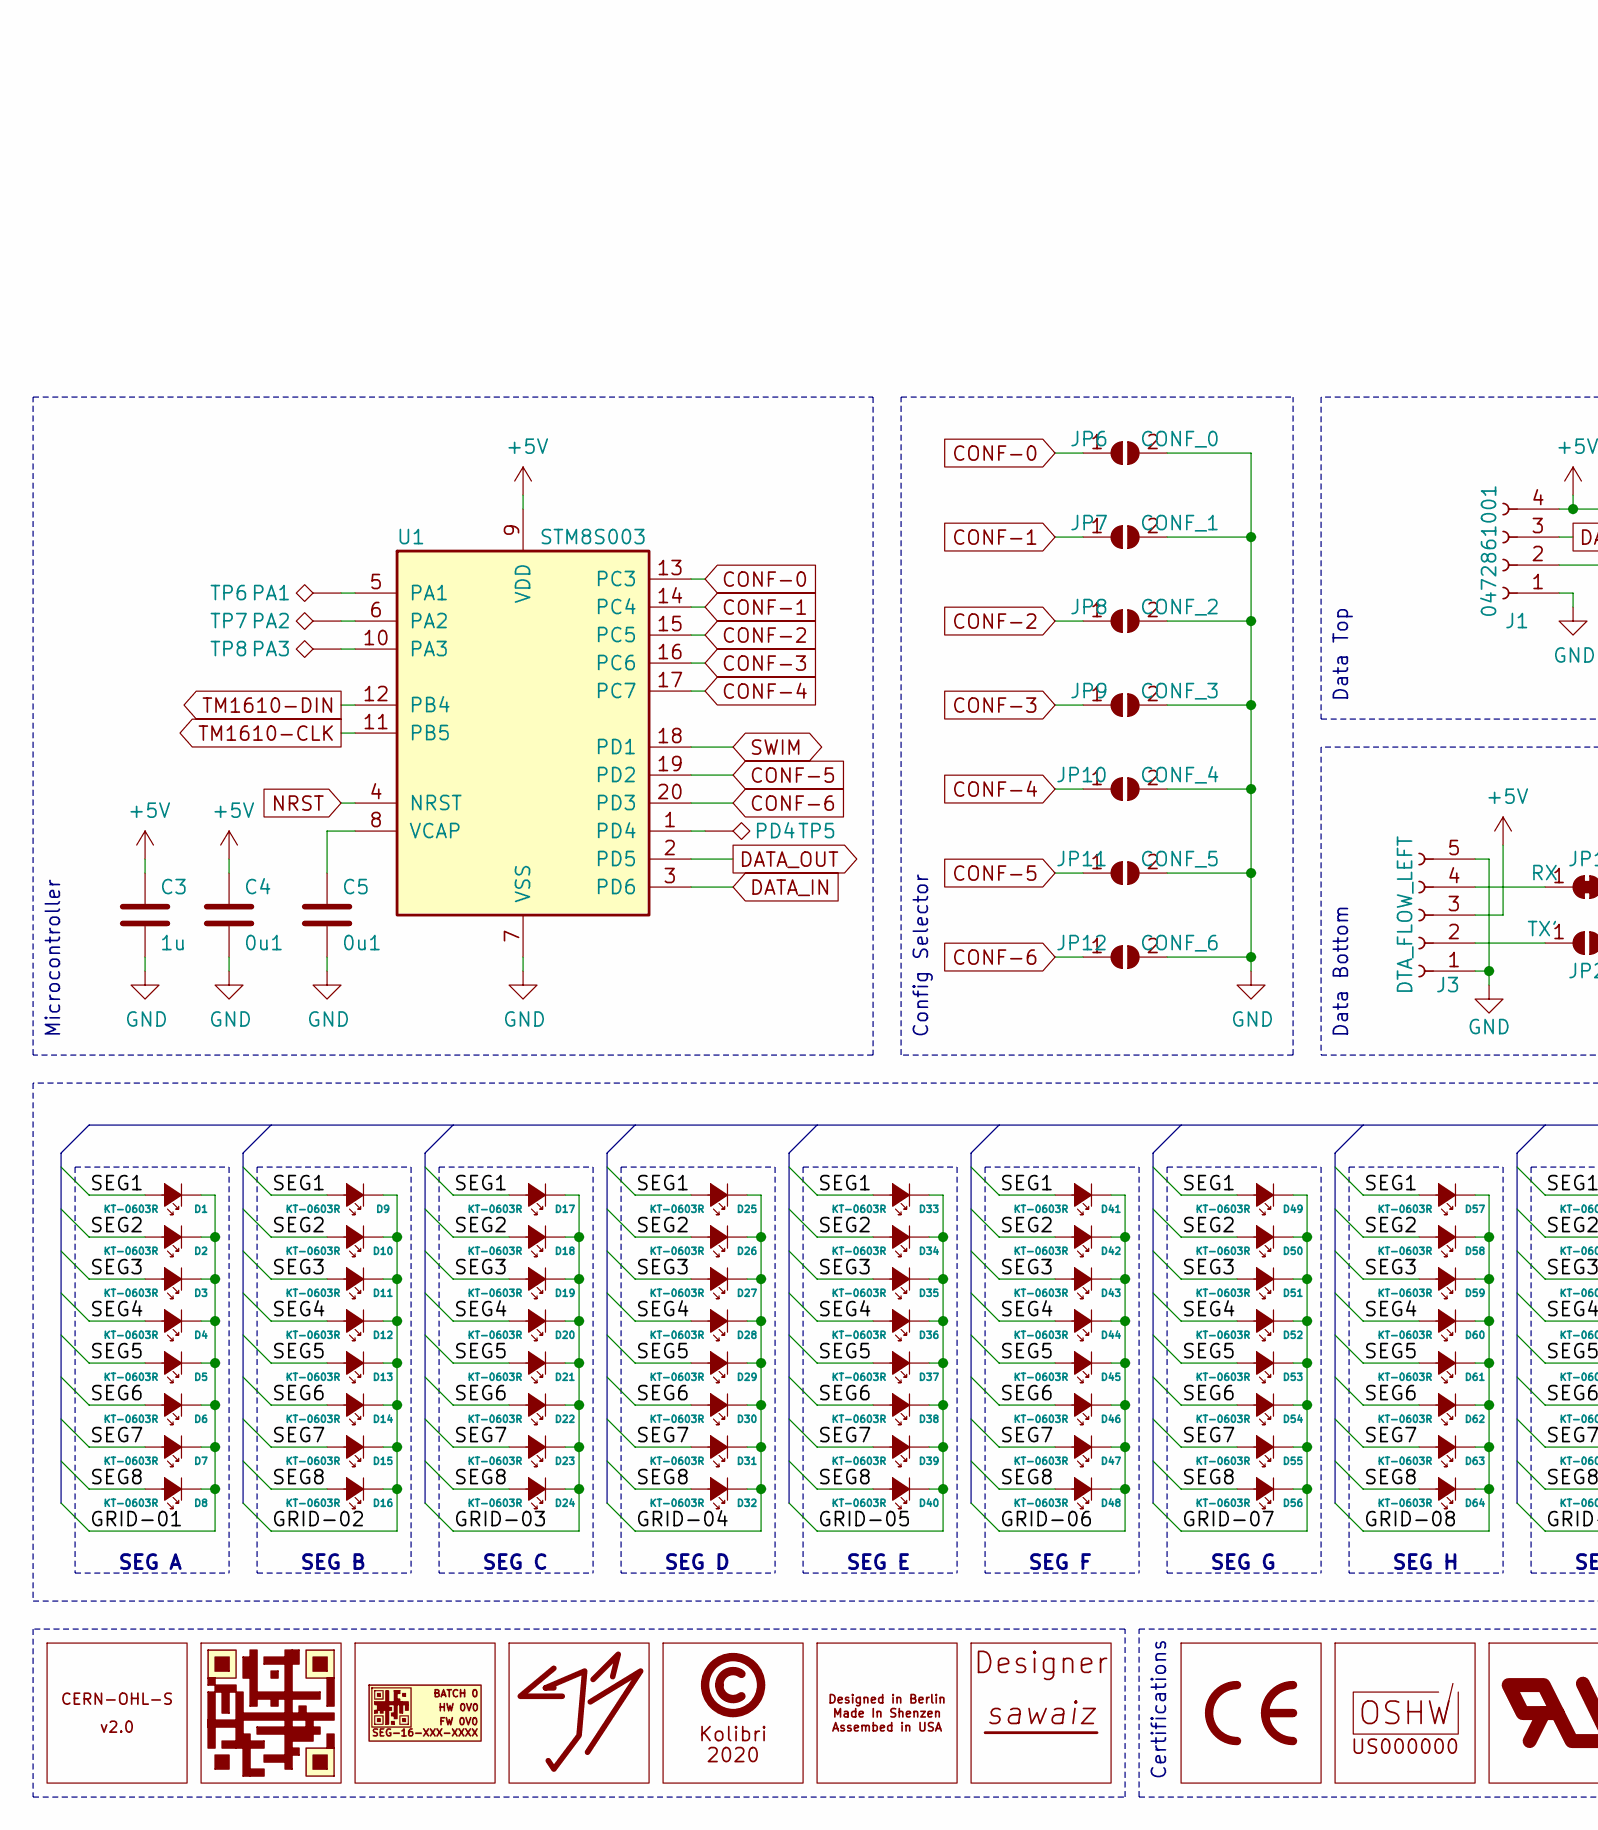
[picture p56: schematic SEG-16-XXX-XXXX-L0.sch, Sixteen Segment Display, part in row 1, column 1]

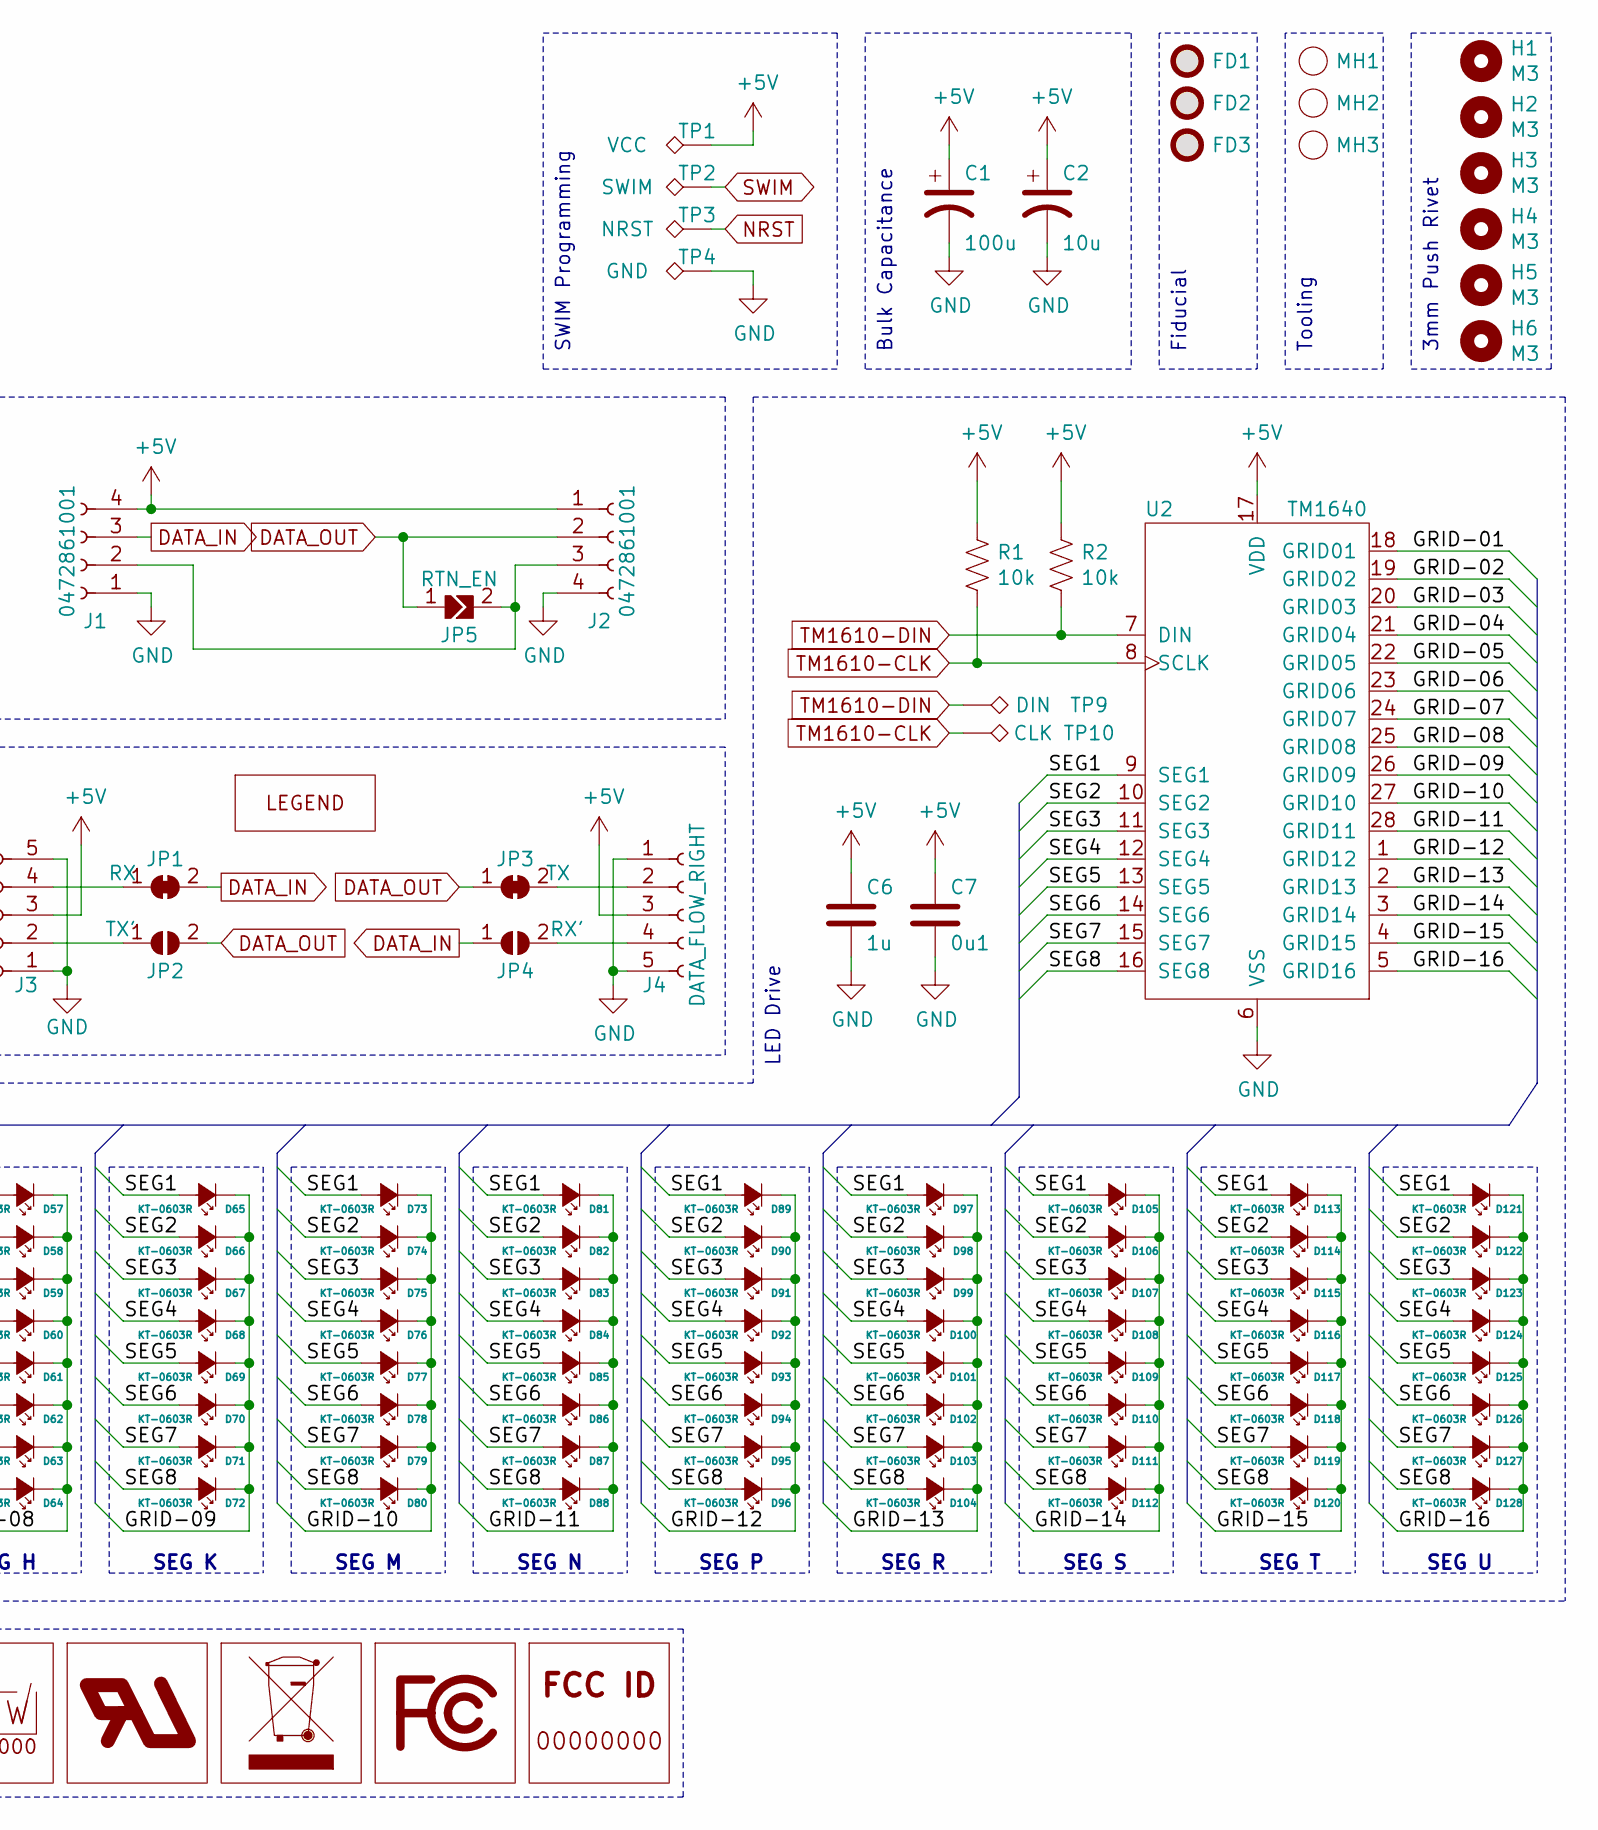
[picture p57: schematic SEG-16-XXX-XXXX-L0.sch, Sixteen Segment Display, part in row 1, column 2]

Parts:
C1: 100u; TAJB
C2: 10u; TAJA
C3, C6: 1u; C_0402
C4, C5, C7: 0u1; C_0402
D1, D2, D3, D4, D5, D6, D7, D8, D9, D10, D11, D12, D13, D14, D15, D16, D17, D18, D19, D20, D21, D22, D23, D24, D25, D26, D27, D28, D29, D30, D31, D32, D33, D34, D35, D36, D37, D38, D39, D40, D41, D42, D43, D44, D45, D46, D47, D48, D49, D50, D51, D52, D53, D54, D55, D56, D57, D58, D59, D60, D61, D62, D63, D64, D65, D66, D67, D68, D69, D70, D71, D72, D73, D74, D75, D76, D77, D78, D79, D80, D81, D82, D83, D84, D85, D86, D87, D88, D89, D90, D91, D92, D93, D94, D95, D96, D97, D98, D99, D100, D101, D102, D103, D104, D105, D106, D107, D108, D109, D110, D111, D112, D113, D114, D115, D116, D117, D118, D119, D120, D121, D122, D123, D124, D125, D126, D127, D128: KT-0603R
FD1, FD2, FD3: Fiducial; Fiducial_1.5mm_Mask3mm
H1, H2, H3, H4, H5, H6: M3; M3-3.1-Tented
J1, J2: 0472861001
J3: DTA_FLOW_LEFT; dataFlowConnector
J4: DATA_FLOW_RIGHT; dataFlowConnector
JP1: RX; SolderJumper-2_P1.3mm_Bridged_RoundedPad1.0x1.5mm
JP2: TX'; SolderJumper-2_P1.3mm_Open_RoundedPad1.0x1.5mm
JP3: TX; SolderJumper-2_P1.3mm_Bridged_RoundedPad1.0x1.5mm
JP4: RX'; SolderJumper-2_P1.3mm_Open_RoundedPad1.0x1.5mm
JP5: RTN_EN; SolderJumper-2_P1.3mm_Open_TrianglePad1.0x1.5mm
JP6: CONF_0; SolderJumper-2_P1.3mm_Open_RoundedPad1.0x1.5mm
JP7: CONF_1; SolderJumper-2_P1.3mm_Open_RoundedPad1.0x1.5mm
JP8: CONF_2; SolderJumper-2_P1.3mm_Open_RoundedPad1.0x1.5mm
JP9: CONF_3; SolderJumper-2_P1.3mm_Open_RoundedPad1.0x1.5mm
JP10: CONF_4; SolderJumper-2_P1.3mm_Open_RoundedPad1.0x1.5mm
JP11: CONF_5; SolderJumper-2_P1.3mm_Open_RoundedPad1.0x1.5mm
JP12: CONF_6; SolderJumper-2_P1.3mm_Open_RoundedPad1.0x1.5mm
MH1, MH2, MH3: toolingHole; 1.152mm-ToolingHole
MK1: CERN-OHL-S_V2.0; CERN-OHL-S_v2.0
MK2: SEG-16-QR
MK3: label
MK4: kolibriBird
MK5: copyright
MK6: designedMadeAssembled
MK7: designer
MK8: CE
MK9: OSHW
MK10: UL
MK11: WEEE
MK12: FCC
MK13: FCCID
MK14: legend
R1, R2: 10k; R_0402
TP1: VCC; TestPoint_Pad_D4.0mm
TP2: SWIM; TestPoint_Pad_D4.0mm
TP3: NRST; TestPoint_Pad_D4.0mm
TP4: GND; TestPoint_Pad_D4.0mm
TP5: PD4; TestPoint_Pad_D1.0mm
TP6: PA1; TestPoint_Pad_D1.0mm
TP7: PA2; TestPoint_Pad_D1.0mm
TP8: PA3; TestPoint_Pad_D1.0mm
TP9: DIN; TestPoint_Pad_D1.0mm
TP10: CLK; TestPoint_Pad_D1.0mm
U1: STM8S003; STM8S003-TSSOP20-6.5x6.4mm
U2: TM1640; SOP28-17.7x7.65

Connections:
+5V: C1.1, C2.1, C3.1, C4.1, C6.1, C7.1, J1.4, J2.1, J3.3, J4.3, R1.1, R2.1, TP1.1, U1.9 (VDD), U2.17 (VDD)
/GRID-01: D1.1 (K), D2.1 (K), D3.1 (K), D4.1 (K), D5.1 (K), D6.1 (K), D7.1 (K), D8.1 (K), U2.18 (GRID01)
/GRID-02: D9.1 (K), D10.1 (K), D11.1 (K), D12.1 (K), D13.1 (K), D14.1 (K), D15.1 (K), D16.1 (K), U2.19 (GRID02)
/GRID-03: D17.1 (K), D18.1 (K), D19.1 (K), D20.1 (K), D21.1 (K), D22.1 (K), D23.1 (K), D24.1 (K), U2.20 (GRID03)
/GRID-04: D25.1 (K), D26.1 (K), D27.1 (K), D28.1 (K), D29.1 (K), D30.1 (K), D31.1 (K), D32.1 (K), U2.21 (GRID04)
/GRID-05: D33.1 (K), D34.1 (K), D35.1 (K), D36.1 (K), D37.1 (K), D38.1 (K), D39.1 (K), D40.1 (K), U2.22 (GRID05)
/GRID-06: D41.1 (K), D42.1 (K), D43.1 (K), D44.1 (K), D45.1 (K), D46.1 (K), D47.1 (K), D48.1 (K), U2.23 (GRID06)
/GRID-07: D49.1 (K), D50.1 (K), D51.1 (K), D52.1 (K), D53.1 (K), D54.1 (K), D55.1 (K), D56.1 (K), U2.24 (GRID07)
/GRID-08: D57.1 (K), D58.1 (K), D59.1 (K), D60.1 (K), D61.1 (K), D62.1 (K), D63.1 (K), D64.1 (K), U2.25 (GRID08)
/GRID-09: D65.1 (K), D66.1 (K), D67.1 (K), D68.1 (K), D69.1 (K), D70.1 (K), D71.1 (K), D72.1 (K), U2.26 (GRID09)
/GRID-10: D73.1 (K), D74.1 (K), D75.1 (K), D76.1 (K), D77.1 (K), D78.1 (K), D79.1 (K), D80.1 (K), U2.27 (GRID10)
/GRID-11: D81.1 (K), D82.1 (K), D83.1 (K), D84.1 (K), D85.1 (K), D86.1 (K), D87.1 (K), D88.1 (K), U2.28 (GRID11)
/GRID-12: D89.1 (K), D90.1 (K), D91.1 (K), D92.1 (K), D93.1 (K), D94.1 (K), D95.1 (K), D96.1 (K), U2.1 (GRID12)
/GRID-13: D97.1 (K), D98.1 (K), D99.1 (K), D100.1 (K), D101.1 (K), D102.1 (K), D103.1 (K), D104.1 (K), U2.2 (GRID13)
/GRID-14: D105.1 (K), D106.1 (K), D107.1 (K), D108.1 (K), D109.1 (K), D110.1 (K), D111.1 (K), D112.1 (K), U2.3 (GRID14)
/GRID-15: D113.1 (K), D114.1 (K), D115.1 (K), D116.1 (K), D117.1 (K), D118.1 (K), D119.1 (K), D120.1 (K), U2.4 (GRID15)
/GRID-16: D121.1 (K), D122.1 (K), D123.1 (K), D124.1 (K), D125.1 (K), D126.1 (K), D127.1 (K), D128.1 (K), U2.5 (GRID16)
/SEG1: D1.2 (A), D9.2 (A), D17.2 (A), D25.2 (A), D33.2 (A), D41.2 (A), D49.2 (A), D57.2 (A), D65.2 (A), D73.2 (A), D81.2 (A), D89.2 (A), D97.2 (A), D105.2 (A), D113.2 (A), D121.2 (A), U2.9 (SEG1)
/SEG2: D2.2 (A), D10.2 (A), D18.2 (A), D26.2 (A), D34.2 (A), D42.2 (A), D50.2 (A), D58.2 (A), D66.2 (A), D74.2 (A), D82.2 (A), D90.2 (A), D98.2 (A), D106.2 (A), D114.2 (A), D122.2 (A), U2.10 (SEG2)
/SEG3: D3.2 (A), D11.2 (A), D19.2 (A), D27.2 (A), D35.2 (A), D43.2 (A), D51.2 (A), D59.2 (A), D67.2 (A), D75.2 (A), D83.2 (A), D91.2 (A), D99.2 (A), D107.2 (A), D115.2 (A), D123.2 (A), U2.11 (SEG3)
/SEG4: D4.2 (A), D12.2 (A), D20.2 (A), D28.2 (A), D36.2 (A), D44.2 (A), D52.2 (A), D60.2 (A), D68.2 (A), D76.2 (A), D84.2 (A), D92.2 (A), D100.2 (A), D108.2 (A), D116.2 (A), D124.2 (A), U2.12 (SEG4)
/SEG5: D5.2 (A), D13.2 (A), D21.2 (A), D29.2 (A), D37.2 (A), D45.2 (A), D53.2 (A), D61.2 (A), D69.2 (A), D77.2 (A), D85.2 (A), D93.2 (A), D101.2 (A), D109.2 (A), D117.2 (A), D125.2 (A), U2.13 (SEG5)
/SEG6: D6.2 (A), D14.2 (A), D22.2 (A), D30.2 (A), D38.2 (A), D46.2 (A), D54.2 (A), D62.2 (A), D70.2 (A), D78.2 (A), D86.2 (A), D94.2 (A), D102.2 (A), D110.2 (A), D118.2 (A), D126.2 (A), U2.14 (SEG6)
/SEG7: D7.2 (A), D15.2 (A), D23.2 (A), D31.2 (A), D39.2 (A), D47.2 (A), D55.2 (A), D63.2 (A), D71.2 (A), D79.2 (A), D87.2 (A), D95.2 (A), D103.2 (A), D111.2 (A), D119.2 (A), D127.2 (A), U2.15 (SEG7)
/SEG8: D8.2 (A), D16.2 (A), D24.2 (A), D32.2 (A), D40.2 (A), D48.2 (A), D56.2 (A), D64.2 (A), D72.2 (A), D80.2 (A), D88.2 (A), D96.2 (A), D104.2 (A), D112.2 (A), D120.2 (A), D128.2 (A), U2.16 (SEG8)
CONF-0: JP6.1 (A), U1.13 (PC3)
CONF-1: JP7.1 (A), U1.14 (PC4)
CONF-2: JP8.1 (A), U1.15 (PC5)
CONF-3: JP9.1 (A), U1.16 (PC6)
CONF-4: JP10.1 (A), U1.17 (PC7)
CONF-5: JP11.1 (A), U1.19 (PD2)
CONF-6: JP12.1 (A), U1.20 (PD3)
DATA_IN: J1.3, JP1.2 (B), JP4.1 (A), U1.3 (PD6)
DATA_OUT: J2.2, JP2.2 (B), JP3.1 (A), JP5.1 (A), U1.2 (PD5)
GND: C1.2, C2.2, C3.2, C4.2, C5.2, C6.2, C7.2, J1.1, J2.4, J3.1, J3.5, J4.1, J4.5, JP6.2 (B), JP7.2 (B), JP8.2 (B), JP9.2 (B), JP10.2 (B), JP11.2 (B), JP12.2 (B), TP4.1, U1.7 (VSS), U2.6 (VSS)
NRST: TP3.1, U1.4 (NRST)
unnamed: C5.1, U1.8 (VCAP)
unnamed: J1.2, J2.3, JP5.2 (B)
unnamed: J3.2, JP2.1 (A)
unnamed: J3.4, JP1.1 (A)
unnamed: J4.2, JP3.2 (B)
unnamed: J4.4, JP4.2 (B)
unnamed: TP5.1, U1.1 (PD4)
unnamed: TP6.1, U1.5 (PA1)
unnamed: TP7.1, U1.6 (PA2)
unnamed: TP8.1, U1.10 (PA3)
SWIM: TP2.1, U1.18 (PD1)
TM1610-CLK: R1.2, TP10.1, U1.11 (PB5), U2.8 (SCLK)
TM1610-DIN: R2.2, TP9.1, U1.12 (PB4), U2.7 (DIN)

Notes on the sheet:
3mm Push Rivet
SEG A
SEG F
SEG C
SEG T
SEG S
SEG R
SEG P
SEG N
SEG M
SEG K
SEG H
SEG G
SEG E
SEG D
SEG B
Bulk Capacitance
SWIM Programming
Tooling
Fiducial
SEG U
Data Top
Data Bottom
Config Selector
Certifications
LED Drive
Microcontroller

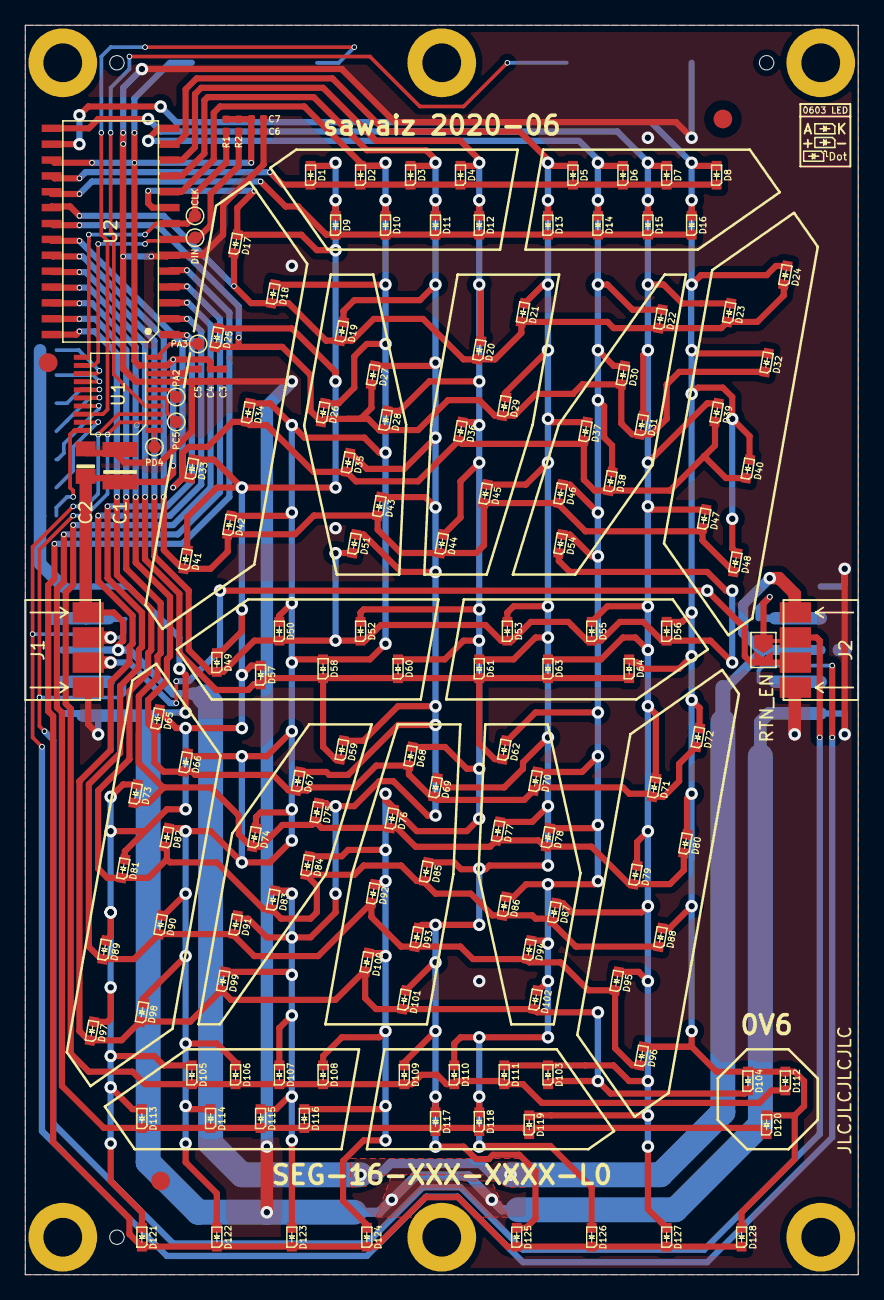
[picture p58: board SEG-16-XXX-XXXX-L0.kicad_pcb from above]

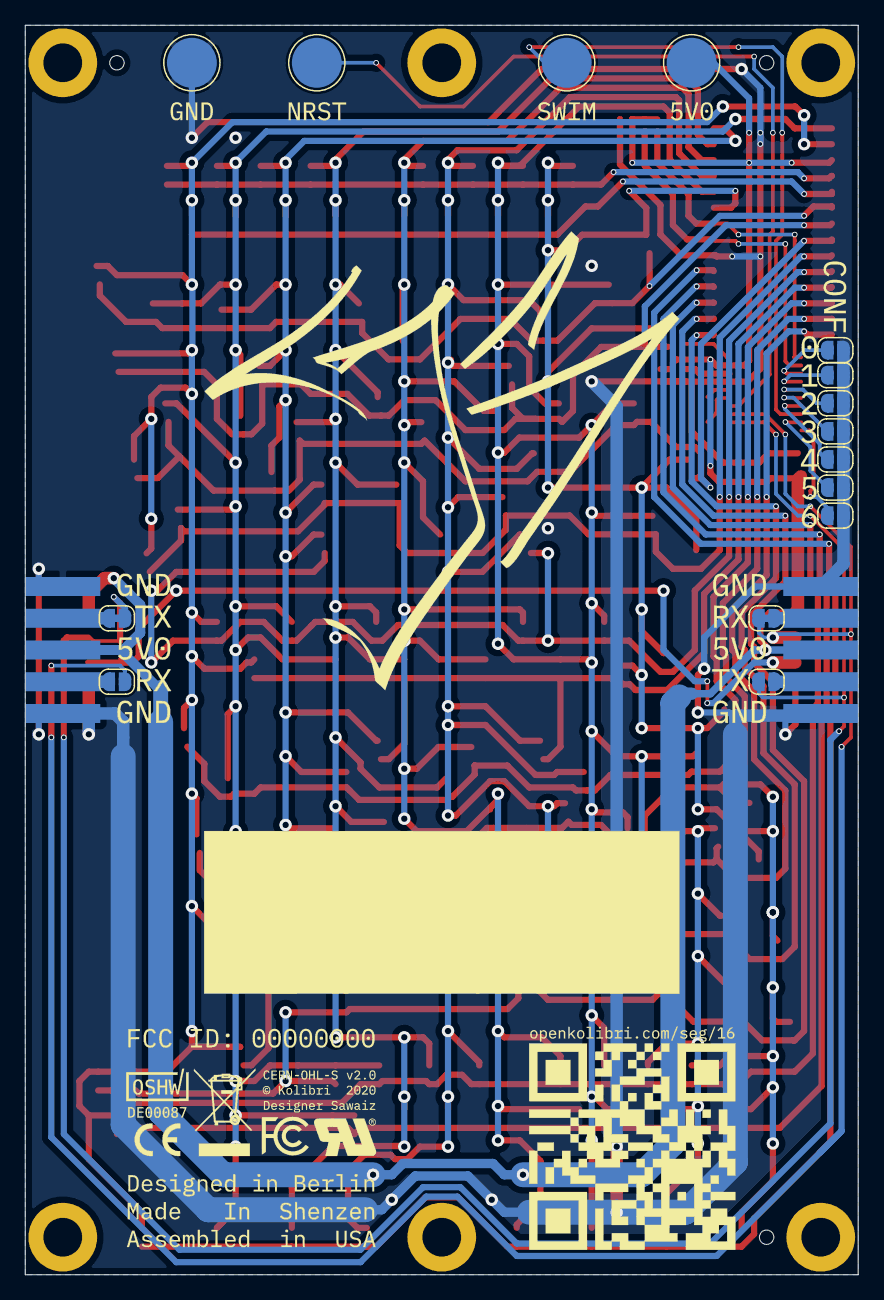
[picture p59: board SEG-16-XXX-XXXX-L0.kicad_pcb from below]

Board: 2 copper layers, 66.7 x 100.0 mm, 191 parts (31 on the bottom side), 49 nets.

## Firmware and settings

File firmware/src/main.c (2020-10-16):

// main.c controller for segmented display
// Copyright (C) 2020 Kolibri - Sawaiz Syed

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
// STM8 Libraries
#include <stm8s.h>

// C Libraries
#include <stdio.h>
#include <string.h>

#include "TM1640.cpp"
#include "TM1640.h"

// [17:17] ASCII mode Current Char/ Control byte
// [15:16] Brightness Control Mode
// [13:16] Segment Control Mode
// [00:16] Led Control Mode
typedef struct DataBuffer {
  unsigned char data[17];
  int8_t txMode;
  int8_t rxMode;
  int8_t marker;
} DataBuffer;
// Default Operating Mode is ASCII
DataBuffer buffer;

// Stores the config read from pads
uint8_t config = 0x00;

// Character Operating Modes
typedef enum Modes {
  ASCII              = 0x00,   // No Control Code
  SEGEMENT_CONTROL   = 0x11,   // DC1
  LED_CONTROL        = 0x12,   // DC2
  BRIGHTNESS_CONTROL = 0x13,   // DC3
  BAUDRATE_CONTROL   = 0x14    // DC4
} Modes;


INTERRUPT_HANDLER(UART1_TX_IRQHandler, 17) {
  switch (buffer.txMode) {
      case LED_CONTROL:
        if (buffer.marker > 0) {
          buffer.marker--;
          UART1_SendData8(buffer.data[buffer.marker]);
        } else {
          // Reset marker postion
          buffer.marker = 16;
          // ASCII mode: Replace buffer with new byte
          buffer.data[16] = UART1_ReceiveData8();
          buffer.txMode = buffer.data[16];
          UART1_ITConfig(UART1_IT_TXE, DISABLE);
        }
        break;

    case SEGEMENT_CONTROL:
      if (buffer.marker > 13) {
        buffer.marker--;
        UART1_SendData8(buffer.data[buffer.marker]);
      } else {
        // Reset marker postion
        buffer.marker = 16;
        // ASCII mode: Replace buffer with new byte
        buffer.data[16] = UART1_ReceiveData8();
        buffer.txMode = buffer.data[16];
        UART1_ITConfig(UART1_IT_TXE, DISABLE);
      }
      break;

    case BRIGHTNESS_CONTROL:
      if (buffer.marker > 15) {
        buffer.marker--;
        UART1_SendData8(buffer.data[buffer.marker]);
      } else {
        // Reset marker postion
        buffer.marker = 16;
        // ASCII mode: Replace buffer with new byte
        buffer.data[16] = UART1_ReceiveData8();
        buffer.txMode = buffer.data[16];
        UART1_ITConfig(UART1_IT_TXE, DISABLE);
      }
      break;

    default:
      // ASCII mode: Replace buffer with new byte
      buffer.marker = 16;
      buffer.data[16] = UART1_ReceiveData8();
      buffer.txMode = buffer.data[16];
      UART1_ITConfig(UART1_IT_TXE, DISABLE);
      break;
  }
}

INTERRUPT_HANDLER(UART1_RX_IRQHandler, 18) {
  // Reset timeout for display refresh
  TIM4_SetCounter(0x00);
  TIM4_ClearITPendingBit(TIM4_IT_UPDATE);
  TIM4_ITConfig(TIM4_IT_UPDATE, ENABLE);

  // Process newly recived Character based on recieve mode
  switch (buffer.rxMode) {
      case LED_CONTROL:
        // Recieve 16 additional bytes for led data
        buffer.data[--buffer.marker] = UART1_ReceiveData8();
        if (buffer.marker < 1) {
          buffer.txMode = LED_CONTROL;
          buffer.rxMode = ASCII;
        }
        break;

    case SEGEMENT_CONTROL:
      // Recieve 3 additional bytes for segment data
      buffer.data[--buffer.marker] = UART1_ReceiveData8();
      if (buffer.marker < 14) {
        buffer.txMode = SEGEMENT_CONTROL;
        buffer.rxMode = ASCII;
      }
      break;

    case BRIGHTNESS_CONTROL:
      // Recieve a additional byte for brightness
      buffer.data[--buffer.marker] = UART1_ReceiveData8();
      buffer.txMode = BRIGHTNESS_CONTROL;
      buffer.rxMode = ASCII;
      break;

    default:
      buffer.rxMode = UART1_ReceiveData8();
      // Forward the current buffered data
      buffer.marker = 16;
      UART1_ITConfig(UART1_IT_TXE, ENABLE);
      UART1_SendData8(buffer.data[16]);
  }
}

// Timer overflow interupt

// Updates the display only when timer overflows and then stops the timer 
// Timer get reset and started when a new charachter has been processed
// Timer duration is 2.5x the baud rate
// So that if multiple charachters are sent in series, the display only updates if 
// a charachter rests in the buffer for over 2.5 charachters.
INTERRUPT_HANDLER(TIM4_UPD_OVF_IRQHandler, 23){
    GPIO_WriteReverse(GPIOD, GPIO_PIN_3);
    TIM4_ITConfig(TIM4_IT_UPDATE, DISABLE);
    switch (buffer.txMode) {
        case LED_CONTROL:
          showLeds(buffer.data);
          break;
        case SEGEMENT_CONTROL:
          showSegments(0x3FFFF & ( (uint32_t)buffer.data[13] << 16 | (uint32_t)buffer.data[14] << 8) |  (uint32_t)buffer.data[15] );
          break;

        case BRIGHTNESS_CONTROL:
          setBrightness(buffer.data[15]);
          break;

        default:
          printLetter(buffer.data[16]);
    }
}



void main() {
  // Clock Prescaler 1, 16MHz
  CLK_HSIPrescalerConfig(CLK_PRESCALER_HSIDIV1);

  GPIO_DeInit(GPIOA);
  GPIO_DeInit(GPIOB);
  GPIO_DeInit(GPIOC);
  GPIO_DeInit(GPIOD);

  // Internal Watchdog
  IWDG_WriteAccessCmd(IWDG_WriteAccess_Enable);    // Enable write access to IWDG registers.
  IWDG_SetPrescaler(IWDG_Prescaler_4);             // IWDG timer clock will be (LSI / 4).
  IWDG_SetReload(0xFF);
  IWDG_ReloadCounter();                            // Reload the IWDG counter.
  IWDG_WriteAccessCmd(IWDG_WriteAccess_Disable);   // Disable write
  IWDG_Enable();                                   // Enable IWDG (LSI will be enabled by hardware).

  // Setup config pins, Input, WeakPullup
  GPIO_Init(GPIOC, GPIO_PIN_3, GPIO_MODE_IN_PU_NO_IT);
  GPIO_Init(GPIOC, GPIO_PIN_4, GPIO_MODE_IN_PU_NO_IT);
  GPIO_Init(GPIOC, GPIO_PIN_5, GPIO_MODE_IN_PU_NO_IT);
  GPIO_Init(GPIOC, GPIO_PIN_6, GPIO_MODE_IN_PU_NO_IT);
  GPIO_Init(GPIOC, GPIO_PIN_7, GPIO_MODE_IN_PU_NO_IT);
  GPIO_Init(GPIOD, GPIO_PIN_2, GPIO_MODE_IN_PU_NO_IT);
  GPIO_Init(GPIOD, GPIO_PIN_3, GPIO_MODE_IN_PU_NO_IT);

  // Read configuration
  config |= !GPIO_ReadInputPin(GPIOC, GPIO_PIN_3) << 0;
  config |= !GPIO_ReadInputPin(GPIOC, GPIO_PIN_4) << 1;
  config |= !GPIO_ReadInputPin(GPIOC, GPIO_PIN_5) << 2;
  config |= !GPIO_ReadInputPin(GPIOC, GPIO_PIN_6) << 3;
  config |= !GPIO_ReadInputPin(GPIOC, GPIO_PIN_7) << 4;
  config |= !GPIO_ReadInputPin(GPIOD, GPIO_PIN_2) << 5;
  config |= !GPIO_ReadInputPin(GPIOD, GPIO_PIN_3) << 6;

  // Set baud rate based on config
  uint32_t bauds[] = {115200, 110, 300, 600, 1200, 2400, 4800, 9600, 19200, 38400, 57600, 128000, 230400, 256000, 460800, 1000000};
  uint32_t baud = bauds[(config & 0X1E) >> 1];
 
  // Starting buffer marker location
  buffer.marker = 16;
  buffer.txMode = ASCII;
  buffer.rxMode = ASCII;
  // Starting charachter is space
  buffer.data[16] = ' ';

  UART1_DeInit();
  // UART1 configured as follow:
  //       - BaudRate = baud
  //       - Word Length = 8 Bits
  //       - One Stop Bit
  //       - No parity
  //       - Receive and transmit enabled
  //       - UART1 Clock disabled
  UART1_Init(baud, UART1_WORDLENGTH_8D, UART1_STOPBITS_1,
             UART1_PARITY_NO, UART1_SYNCMODE_CLOCK_DISABLE,
             UART1_MODE_TXRX_ENABLE);
  UART1_ITConfig(UART1_IT_RXNE_OR, ENABLE);
  UART1_Cmd(ENABLE);

  // Display refresh timer
  //   - CLK = 16 MHZ
  //   - DIV 128
  //   - OVF @ 125
  //   - 1ms
  TIM4_DeInit();
  TIM4_TimeBaseInit(TIM4_PRESCALER_128, 125);
  TIM4_ITConfig(TIM4_IT_UPDATE, ENABLE);
  TIM4_Cmd(ENABLE);

  // Enable interupts
  enableInterrupts();

  // Set PB3 to Push pull
  GPIO_Init(GPIOD, GPIO_PIN_3, GPIO_MODE_OUT_PP_LOW_FAST);

  tm1640Init(GPIOB, GPIO_PIN_5, GPIOB, GPIO_PIN_4);
  setBrightness(BRIGHTNESS_14);
  printLetter(buffer.data[buffer.marker]);

  while (1) {
    // Reload the watchdog timer while wating
    IWDG_WriteAccessCmd(IWDG_WriteAccess_Enable);
    IWDG_ReloadCounter();
    IWDG_WriteAccessCmd(IWDG_WriteAccess_Disable);
  }
}

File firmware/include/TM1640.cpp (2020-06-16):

#include "TM1640.h"

static GPIO_TypeDef*  _tm1640ClkPort;
static GPIO_Pin_TypeDef _tm1640ClkPin;
static GPIO_TypeDef*  _tm1640DioPort;
static GPIO_Pin_TypeDef _tm1640DioPin;

void tm1640Init(GPIO_TypeDef* clkPort, GPIO_Pin_TypeDef clkPin, GPIO_TypeDef* dioPort, GPIO_Pin_TypeDef dioPin) {
  _tm1640ClkPort = clkPort;
  _tm1640ClkPin = clkPin;
  _tm1640DioPort = dioPort;
  _tm1640DioPin = dioPin;

  // Initalsize GPIO
  GPIO_WriteHigh(clkPort, clkPin);
  GPIO_WriteHigh(dioPort, dioPin);
  GPIO_Init(clkPort, clkPin, GPIO_MODE_OUT_PP_LOW_FAST);
  GPIO_Init(dioPort, dioPin, GPIO_MODE_OUT_PP_LOW_FAST);

  setBrightness(BRIGHTNESS_01);

  uint8_t data[] = {AUTO_INC_ADDR};
  sendCommand(data, 1);
}

void setBrightness(brightness value){
    uint8_t data[]= {value};
    sendCommand(data, 1);
}

void printLetter(char letter) {
  showSegments(SixteenSegmentASCII[letter - 32]);
}

void showSegments(uint32_t charMap) {
  uint8_t buffer[17] = {0};
  buffer[0] = 0xC0;
  for (int i = 0; i < 18; i++) {
    if (charMap >> i & 1) {
      for (int j = 0; j < segmentElements[i]; j++) {
        // Calculate the segment and grid mapping
        uint8_t grid = ((segments[i][j] - 1) / 8) + 1;
        uint8_t seg = (segments[i][j] - 1) % 8;
        buffer[grid] |= 1 << seg;
      }
    }
  }
  sendCommand(buffer, 17);
}

void showLeds(uint8_t *data) {
  uint8_t buffer[17] = {0};
  buffer[0] = 0xC0;
  for(int i = 1 ; i < sizeof(buffer) ; i++){
      buffer[i] = data[16-i];
  }
  sendCommand(buffer, 17);
}

void sendCommand(uint8_t data[], uint8_t length) {
  // TM1640_DIN LOW
  GPIO_WriteLow(TM1640_PORT, TM1640_DIN);
  // TM1640_CLK LOW
  GPIO_WriteLow(TM1640_PORT, TM1640_CLK);
  for (int i = 0; i < length; i++) {
    sendByte(data[i]);
  }
  // TM1640_CLK HIGH
  GPIO_WriteHigh(TM1640_PORT, TM1640_CLK);
  // TM1640_DIN HIGH
  GPIO_WriteHigh(TM1640_PORT, TM1640_DIN);
}

void sendByte(uint8_t byte) {
  for (int i = 0; i < 8; i++) {
    if (byte & 0x01 << i) {
      GPIO_WriteHigh(TM1640_PORT, TM1640_DIN);
    } else {
      GPIO_WriteLow(TM1640_PORT, TM1640_DIN);
    }
    // Toggle TM1640_CLK Twice
    GPIO_WriteHigh(TM1640_PORT, TM1640_CLK);
    GPIO_WriteLow(TM1640_PORT, TM1640_CLK);
  }
  // TM1640_DIN HIGH
  GPIO_WriteLow(TM1640_PORT, TM1640_DIN);
}

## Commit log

2020-06-19 Updated to 0V6 changed images
    [SEG-16-XXX-MDNT-L3.kicad_pcb, SEG-16-XXX-NOON-L3.kicad_pcb, SEG-16-XXX-XXXX-L0.kicad_pcb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]
2020-06-24 Correct voltage spelling
2020-06-25 Added current profiles for B14-B4
2020-06-28 Fixed links and document flow
2020-06-28 Current test stand info added
2020-06-28 Updated mini current table
2020-10-16 Added WDT to display code
    [SEG-16-XXX-XXXX-L0.kicad_pcb]
2021-01-25 Change ""nM" to "nm" in BOM
2021-01-28 Reverted version to kicad 5.x, fixed OSHW Marking, added better led markings and legend
    [SEG-16-XXX-XXXX-L0.kicad_pcb]

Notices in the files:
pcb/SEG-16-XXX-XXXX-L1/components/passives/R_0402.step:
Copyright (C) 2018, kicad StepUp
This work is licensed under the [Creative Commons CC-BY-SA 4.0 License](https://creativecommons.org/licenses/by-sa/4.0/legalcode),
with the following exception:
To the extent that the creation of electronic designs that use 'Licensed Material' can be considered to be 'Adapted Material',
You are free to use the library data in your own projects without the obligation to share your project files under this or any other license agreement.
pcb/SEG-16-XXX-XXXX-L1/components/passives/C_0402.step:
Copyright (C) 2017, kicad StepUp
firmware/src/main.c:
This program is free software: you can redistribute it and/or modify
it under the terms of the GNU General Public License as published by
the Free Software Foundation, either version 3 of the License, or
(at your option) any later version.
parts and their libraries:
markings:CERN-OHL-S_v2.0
